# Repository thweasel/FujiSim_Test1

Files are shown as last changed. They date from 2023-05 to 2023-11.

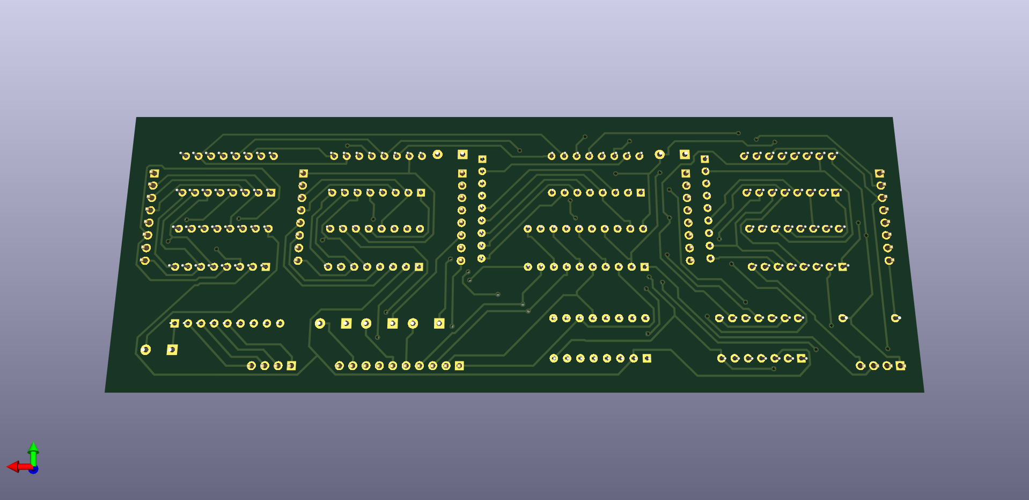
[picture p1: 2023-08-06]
KiCad7/Z80Bus_Adapters/ZXspectrum_Concept_v2/Impl/SPI-Z80-BUS_ZXspectrum_impl_V2/SPI-Z80-BUS-ZXSpectrum_impl_V2-back.png

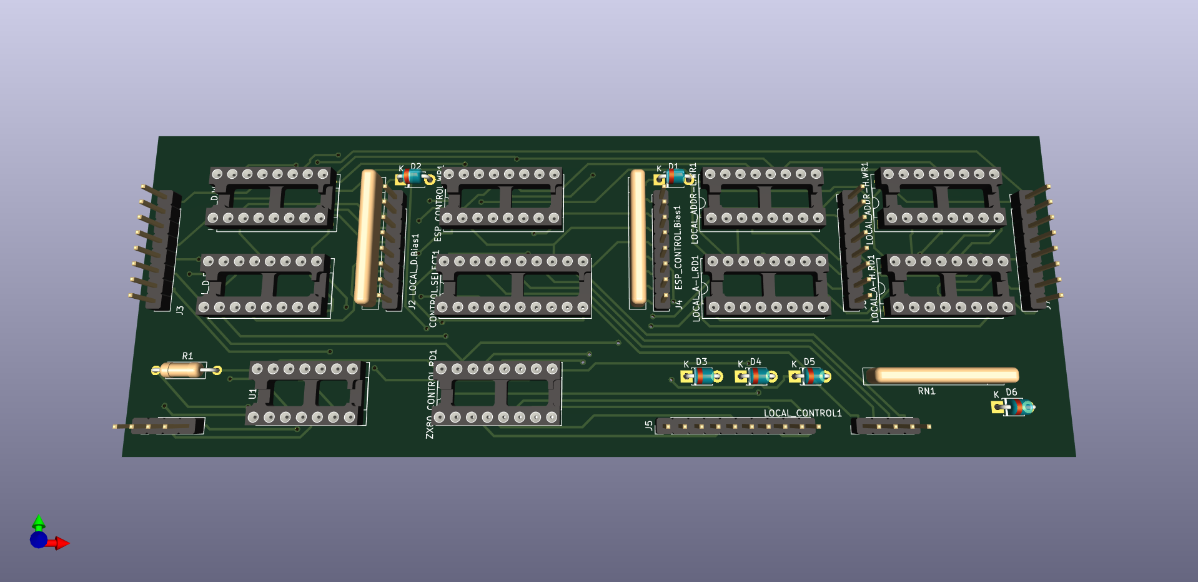
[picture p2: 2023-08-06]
KiCad7/Z80Bus_Adapters/ZXspectrum_Concept_v2/Impl/SPI-Z80-BUS_ZXspectrum_impl_V2/SPI-Z80-BUS-ZXSpectrum_impl_V2-front.png

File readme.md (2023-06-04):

# FujiNet Z80 simulation

The repo contains a SimulIDE simulator circuit with an Ardunio Mega to simulate Z80 and ESP signalling to the proposed bus interface.

Platform IO should be used within Visual Code to compile the project which is based on Arduino libraries.

## SimulIDE simulation settings

**SimulIDE Version0.4.15SR10**

To accurately simulate the SPI timing the properties of the simulation need to be edited before running. The "Simu Step ns" needs to be set to 10 in SimulIDE (right click empty diagram space, select properties from pop up menu). If simulation step time is not set correctly, then the ESP simulation will see bits missing when reading the Shift registers as the Clock and data signalling slips.

Don't forget to load the Firmware file into the Arduino! PlatformIO compiles the Arduino code to ./.pio/megaatmega2560/firmware.hex, when you click Build (not Build and program unless you are using real hardware!)

## KiCad ##

**KiCad version 7**

Going forward there are going to be different ways that the modules can be implemented and built. Therefore, a set of KiCad projects are in a modules folder, and then there is a folder for libraries for symbols/footprints; these are the building blocks. 

Each module project should have 2 schematics. The main project schematic has Pin headers etc. for a (test) PCB and a hierarchical schematic (not a project just a file) that contains the module's circuit. The module's hierarchical schematic file should not contain any connectors or "PCB stuff" just the parts needed for its function. So when making an adaptor the nested hierarchical schematic can be imported this hierarchical schematic without the extra "PCB stuff" cluttering the adaptor project PCBs. Module projects do not need a PCB design as they are imported into other projects that implement the PCB design and associated connectors etc. However, I like the idea of the modules being projects which have a PCB design to create a physical implementation for testing. In time all the modules could follow some common standard for PCB implementation these could be built and wired up ad-hoc.

A reference design is in the root KiCad folder, this shows how everything should connect up to make an adapter. There shouldn't really be a PCB for the reference design as the PCB design can (and did) influence the schematic. The reference design should be a pure, readable and simple expression of the requirements. So going forward a KiCad project should be created for the adaptor being built (in the adaptors folder), a simple way to copy all the settings is to save as from a similar project (e.g. template project). Now the modules schematics can be added to the adaptor project hierarchical schematics, add their hierarchical pins and wire/label as required.

If an adaptor uses a daughter board, then sub-projects in the adapter project need to be created (so they have their own PCB design). The sub-project is imported to the adaptor's main project as a hierarchical schematic so that the Electronic Rule Checker (ERC) can be used to validate the design.  Don't try to mark one-eye ball an adaptor design there are multiple busses and logic signals, and it's not far off a small computer; ERC is a valuable tool so use it. Another trick is to make use of the BUS net Class directives which apply styling to the connected bus, if a connection is missing there is no styling applied. I like to make it easy to see when things aren't connected as sometimes the ERC won't report a problem (more than one pin is connected makes it valid, even if it should be 3 pins connected).

## PCB fabrication with a 3018 CNC mill

The software pipeline:
- KiCad PCB design (export Gerber and Drill files)
- pcb2gcode (CAM, gerber to gcode)
- Universal Gcode Sender (runs the CNC mill controller)

The size and accuracy of the mill determine the PCB design rules to be used in the KiCad board setup. 

After trial and error, the following minimum limits have been found. A 0.5mm end mill (cutter) requires at a minimum, 0.4mm tracks and 0.6mm clearances. (This may change with pcb2gcode and some "git-gud"). With a 200-watt spindle motor, the following speeds and feeds for drilling and milling with a 0.5mm end mill.

Drilling
- Z cut -2mm
- Z Feedrate 30
- Spindle Speed 600 (~60% power)

Milling
- Z cut -0.15mm (board thickness varies)
- X-Y Feedrate 60 (20 or 40)
- Z Feedrate 30
- Spindle speed 800 (~80% power)

Going slower seems to be better for accuracy and success. Running the milling at max spindle speed and -1.5 cut resulted in a snapped 0.5mm end mill. Also, there is a lot of noise/vibration which makes the cutting just sound wrong.

The choice of tool for cutting the isolation paths seems to be split between V-bits and tiny straight-end mills. V-bits have a tip as narrow as 0.1mm but widen based on the angle (degrees) of the V. Assuming a perfectly flat board of even thickness, the tip + width at depth (0.1mm) isolation paths can be cut; assume a width of ~0.2mm approximately. However, perfect doesn't exist, the bit moves as Z height but the surface height changes (PCB thickness, bowing etc.). Therefore, the cut width changes as the V shape angle produces wider cuts as the tip moves deeper into the material. An end mill has a straight edge so cuts consistently at all depths below the surface. The only concern is cutting too deep and breaking the end mill, which is why a 0.5mm bit is used. End mills or Ball cutters go down to 0.2mm, but breakage risks increase. There is a similar problem with V bits, a 20-degree angle has a weaker tip than a 60-degree angle V bit. A wider angle V bit cut widens quicker with slight changes in depth. There is no perfect tool, just compromises and different workflows.

To counter problems with Vbits and depth of cut, Universal Gcode Sender has a plugin called "AutoLeveler". This plugin probes the height of the PCB at some given intervals. A height map is generated and the Z positions in the Gcode are modified. Thus, adding to the process of milling per side, probing pass and transformation of gcode. The accuracy of the trace is subject to the resolution of the probing, high accuracy means probing more points (long time). To conclude, there is room to achieve thinner track and clearance but for now, a simpler reliable approach trumps mastery of PCB milling.

Milling two-sided PCBs require the board to be flipped. This is an immediate alignment challenge which needs some thought. There are limitations imposed by CAM software features and the size of the CNC mill. Typically, the method seems to be prescribed by the CAM software. FlatCAM does inbox flips, the board is in the same place on the bed. To do this FlatCAM provides support to flip/mirror one of the Gerbers, alignment drill holes can be easily added. However, FlatCAM is too manual and buggy. 

Pcb2gcode enables "millproject" config files to be set up and reused between projects. The flip method used is a page turn by default, which requires the bed to be twice the size of the PCB. With a small bed and a big board, an in-place flip can be achieved by re-zeroing the origin on the X-axis after the flip.  Ideally, a jig should be used to maintain X-Y alignment or alternatively a pair of alignment holes evenly spaced from the centre lines. To make the flip alignment accurate an alignment hole can be drilled at 0,0 on the front; when flipped re-align to the hole and reset X 0. If you don't want to make holes in a PCB that is cut accurately to size, then zero on the corners (with the same tool fitted each time).

### KiCad PCB design/settings

Before laying out the PCB you need to set up the board settings, Design Rules and Net Classes. these should be set based on the achievable tollerances of the milling process.

Auto routing (FreeRouting) ignores the Design Rules, it only seems to follow NetClass rules, Edges and Margins (Rule areas on the margin layer). Therefore, you should fully define the board before placing components!

The process sets are:
Configure Design Rules and Net Classes
Draw an Edge box to the size of the PCB
Set Origin (file/drill/sheet) in the top left of the Edge box - place a *VIA on this spot
Create Margin boxes (+2mm) on the edges (Rule Area)
Layout components
Route tracks
Export Gerber and drill files (include the origins)
Export SVG as a CNC reference. F.Cu, B.Cu, User.Drawings, Edge.Cuts, F.Fab, B.Fab

*Directly placing a VIA on the Origin is blocked if it is in the margin. To get round this place the VIA outside the margin and move it to the Origin, this is permitted. Else you could adjust the shape of the marging and expose the corner.

Your PCB should have an Edge box the size of the PCB (stock or cut out). Marked out margins for Freerouting, 2mm seems reasonable. The Origin for sheets and files needs to be set at the top left of the Edge box. Origin can be corrected in pcb2gcode and milling just saves effort to do it right. Export to Gerber (Fabrication output), make sure "Use drill/place file origin" is checked. Hit Plot and Generate Drill Files. If you want to be tidy, export only the F.Cu, B.CU, and Edge_Cuts. You have a PCB file set to run through pcb2gcode.

The KiCad process is done!

### pcb2gcode CAM 

A "millproject" needs to be configured which enables milling a PCB with the Design Rules defined in KiCad. Yep, this is a circular dependency! 

Each Gerber needs to be addressed directly in the millproject file. Given the KiCad naming scheme, a bash script with a command line config can be used to wildcard the files. E.g. "pcb2gcode --front=*-F_Cu.gbr".

Read the wiki to create the millproject file https://github.com/pcb2gcode/pcb2gcode/wiki/Manual

Examples can be found in the pcb2gcode folder.

### Milling procedure

Set up a jig on the bed to hold the PCB.

Start with the front processes, which all have positive X co-ordinates

**Alignment**
- Align the mill and zero on the origin TOP-LEFT (same as KiCad)
- Use the PCB corner (marker pen) OR drill an alignment hole for the origin

**Drilling - front**
- Use drill bits that are the same length butted up in the collet, save  zeroing the Z axis per bit.
- Fit the first Tool (drill bit) in drill.ngc
- Touch the bit on the surface of the board and set Z to zero
- Run the drill.ngc
- Change bits as prompted.

**Milling - front**
- Fit the 0.5mm end mill
- Touch bit on the PCB surface and 0 Z axis
- Run Front.ngc

**Flip on Y (left to right)**
- The default flip/mirror axis in pcb2gcode is along the left edge of the - PCB, "turning a page in a book".
- Measure the X-axis length, move the mill from 0,0 lenght+X
- The mill should now be aligned to the TOP-RIGHT corner, opposite the origin used for the front.
- Tune positioning
- RESET X to 0

All cuts on the Back.ngc have a negative X coordinate so the mill runs from right to left.

**Milling - back**
- Fit the 0.5mm end mill
- Touch bit on the PCB surface and 0 Z axis
- Run Back.ngc

**Cut out - optional**
- Fit a cutting end mill (3.127mm)
- Touch bit on the PCB surface and 0 Z axis
- Run Outline.ngc

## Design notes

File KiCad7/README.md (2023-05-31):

# KiCad projects

Folders:

**Adapters** projects to make FujiNet adapters for different machines.

**Modules** parts to import into adapters for common functions e.g. SPI bus.

**Modules/*_impl** modules implemented as stand-alone PCBs with connectors

**ReferenceDesign** is an example of a completed adapter (schematic) for a ZX spectrum. This is the current concept design.

## New projects and path management

Some KiCad referencing information because managing paths is a tad annoying. Use relative pathing if you want anyone to open something you made. To do this all paths should start ${KIPRJMOD} which is the environment variable for the project folder ../ will take you back one layer as expected.

If you want to start a new Module or Adapter then you should open the template project and SAVE AS "name". This will copy the template and setting for you, and then there is less to set up.  Setting up from scratch requires libraries importing, Net classes, buses, PCB settings etc set up.

### Symbols

Name: esp32-wrover
Path: ${KIPRJMOD}/../../FujiNet_KiCadLibs/esp32-wrover-kicad-master/esp32-wrover.lib

Name: FujiNet_Memory_RAM
Path: ${KIPRJMOD}/../../FujiNet_KiCadLibs/FujiNet_Memory_RAM.kicad_sym

### Footprints
Name: esp32-wrover
Path: ${KIPRJMOD}/../../FujiNet_KiCadLibs/esp32-wrover-kicad-master/esp32-wrover.pretty

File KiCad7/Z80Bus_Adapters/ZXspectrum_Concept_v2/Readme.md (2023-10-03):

 
# ThatOldNerd's Revision 2 

ThatOldNerd's hard work to turn all the simulation circuit changes back into useable schematics and PCB layout.

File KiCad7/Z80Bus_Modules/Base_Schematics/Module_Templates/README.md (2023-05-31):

# New Module setup

Open the Modules project in this folder and SAVE AS "name" in the folder level above. Then open and SAVE AS the Module_Project_impl into the new Modules project (make a nested project).

A module has a project to manage the library paths. Some modules will need parts in the FujiNet Library. The nested project should have the same name as the module with _impl on the end. This sub-project is for creating an implementation of the module. Ideally, the PCB should have connectors/pin headers to enable testing of the module.

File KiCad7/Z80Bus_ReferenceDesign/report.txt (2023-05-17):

Change symbols J? J10 J9 J10 J1 from 'Connector_Generic:Conn_02x25_Top_Bottom' to 'Connector_Generic:Conn_02x25_Top_Bottom': OK

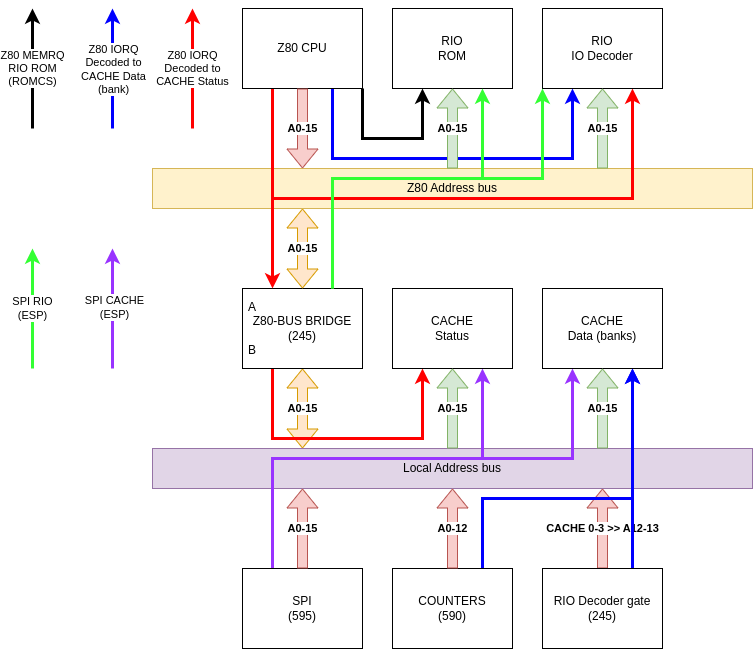
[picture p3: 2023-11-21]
Docs/Address BUS Block diagram Signal paths.drawio.png

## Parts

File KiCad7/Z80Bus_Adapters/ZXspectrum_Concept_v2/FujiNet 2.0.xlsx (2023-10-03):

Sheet: FujiNet 2.0
Designator | Description | Value
R1, R2, R3, R4 | R_Axial_DIN0207_L6.3mm_D2.5mm_P10.16mm_Horizontal | 22K
RN1 | R_Array_SIP9 | 4609M-101-103LF
C1, C2 | CP_Radial_D8.0mm_P5.00mm | 10uf
C3, C4, C5, C6 | C_Disc_D7.5mm_W2.5mm_P5.00mm | 0.1uf
D1, D2, D3, D4, D5, D6 | D_T-1_P5.08mm_Horizontal | 1N4148
Z80_AddLow, Z80_AddHigh | DIP-20_W7.62mm_Socket | 74HC245N
IC1 | DIP-14_W7.62mm_Socket | 7404N
IC2, IC5, IC7 | DIP-14_W7.62mm_Socket | 74HC32N
IC3 | DIP-14_W7.62mm_Socket | 7474N
IC4, IC6, IC8 | DIP-14_W7.62mm_Socket | 74HC08N
U1 - ESP32-WROVER-DEV-MODULE | Controller Daughter Board
U2 | DIP-14_W7.62mm | 74HC00
U3 | DIP-20_W7.62mm_Socket | 74HC244N
J1 | PinHeader_1x04_P2.54mm_Vertical
J2 - LOCAL_D | PinHeader_1x08_P2.54mm_Vertical
J3 - ESP_SPI_INT | PinHeader_1x08_P2.54mm_Vertical
J4 - ESP_CONTROL | PinHeader_1x08_P2.54mm_Vertical
J5 - Z80_CONTROL | PinHeader_1x10_P2.54mm_Vertical
J6 - LOCAL_A-L | PinHeader_1x08_P2.54mm_Vertical
J7 - LOCAL_A-H | PinHeader_1x08_P2.54mm_Vertical
J8 - DIAG-HOST_SYSTEM_BUS | PinHeader_1x40_P2.54mm_Vertical
J10 | PinHeader_1x04_P2.54mm_Vertical
EX_SPI1 | PinSocket_1x06_P2.54mm_Vertical
CACHE2 | PinSocket_1x14_P2.54mm_Vertical
LOCAL_CONTROL | PinHeader_1x04_P2.54mm_Vertical

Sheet: IOCACHE-128K
Designator | Description | Value
R1 | R_Axial_DIN0207_L6.3mm_D2.5mm_P10.16mm_Horizontal | 10K
IC1, IC2 | DIP-16_W7.62mm_Socket | 74HC590N
CACHE1 | DIP-32_W15.24mm_Socket | AS6C1008-55PCN
CACHE2 | PinSocket_1x24_P2.54mm_Vertical
CACHE3 | PinSocket_1x14_P2.54mm_Vertical

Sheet: RIO Board
Designator | Description | Value
R1, R2, R3 | R_Axial_DIN0207_L6.3mm_D2.5mm_P10.16mm_Horizontal | 10K
RIO_DECODER1 - Z80-RIO_DATA1 | DIP-20_W7.62mm_Socket | 74HC245N
RIO1 | DIP-32_W15.24mm_Socket | AS6C1008-55PCN
J1 | PinSocket_1x24_P2.54mm_Vertical
J2 | PinSocket_1x18_P2.54mm_Vertical

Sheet: SPI Buss
Designator | Description | Value
R1 | R_Axial_DIN0207_L6.3mm_D2.5mm_P10.16mm_Horizontal | 22K
RN1 - LOCAL_CONTROL.Bias, ESP_CONTROL.Bias1, LOCAL_D.Bias1 | R_Array_SIP9 | 10k
D1, D2, D3, D4, D5 | D_T-1_P5.08mm_Horizontal | 1N4148
U1 | DIP-14_W7.62mm_Socket | 74HC00
ZX80_CONTROL.RD1, LOCAL_D.RD1, LOCAL_A-H.RD1, LOCAL_A-L.RD1 | DIP-16_W7.62mm_Socket | 74HC165N
LOCAL_D.WR1, ESP_CONTROL.WR1, LOCAL_ADDR-H.WR1, LOCAL_ADDR-L.WR1 | DIP-16_W7.62mm_Socket | 74595N
CONTROL.SELECT1 | DIP-20_W7.62mm_Socket | 74HC244N
LOCAL_CONTROL1 | PinHeader_1x04_P2.54mm_Vertical
J1 | PinHeader_1x04_P2.54mm_Vertical
J2 - LOCAL_D | PinHeader_1x08_P2.54mm_Vertical
J3 - ESP_SPI_INT | PinHeader_1x08_P2.54mm_Vertical
J4 - ESP_CONTROL | PinHeader_1x08_P2.54mm_Vertical
J5 - Z80_CONTROL | PinHeader_1x10_P2.54mm_Vertical
J6 - LOCAL_A-L | PinHeader_1x08_P2.54mm_Vertical
J7 - LOCAL_A-H | PinHeader_1x08_P2.54mm_Vertical

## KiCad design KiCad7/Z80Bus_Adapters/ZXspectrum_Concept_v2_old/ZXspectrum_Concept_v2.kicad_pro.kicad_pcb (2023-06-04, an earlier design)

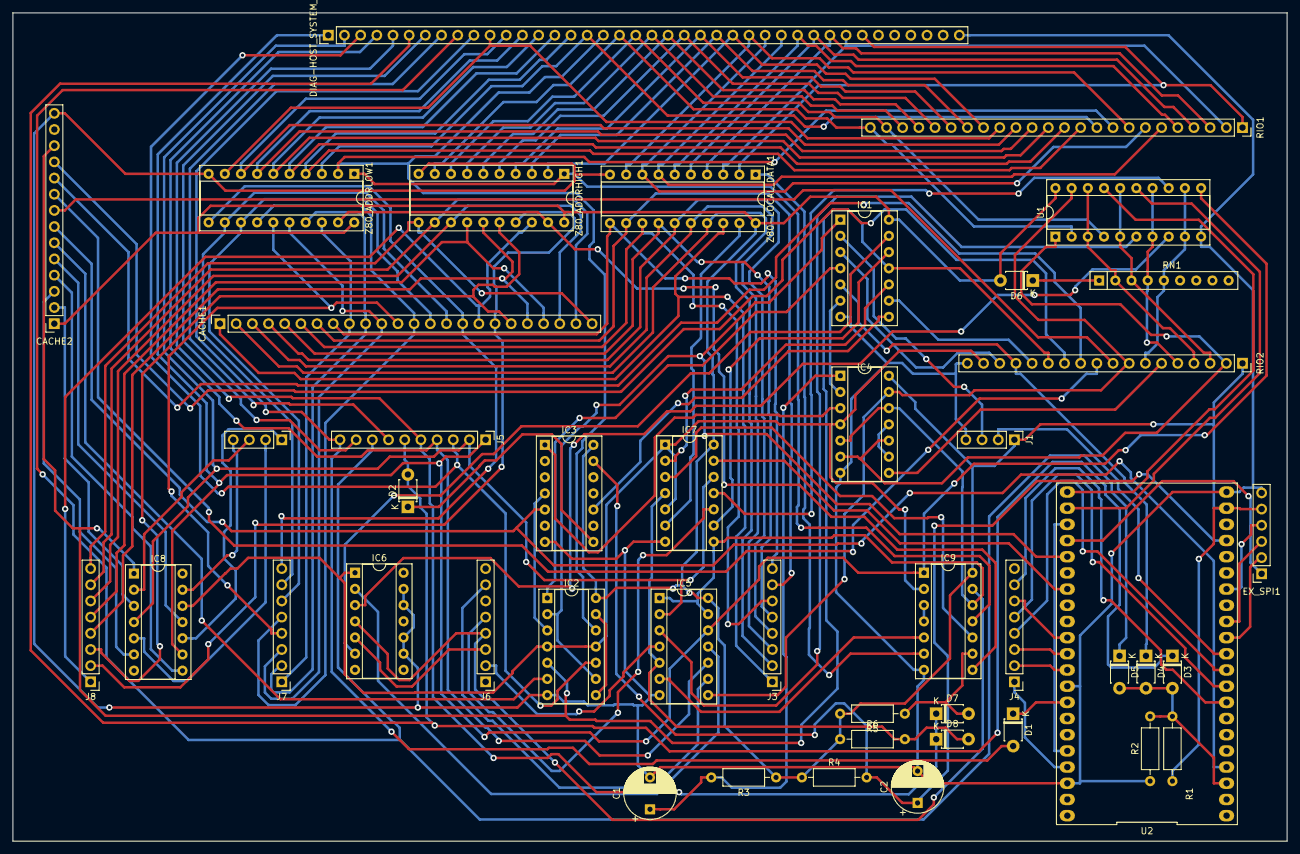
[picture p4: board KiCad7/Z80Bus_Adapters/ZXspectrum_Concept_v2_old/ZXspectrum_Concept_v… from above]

Board: 2 copper layers, 200.0 x 130.0 mm, 45 parts (0 on the bottom side), 139 nets.

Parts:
C1, C2: 10UF; CP_Radial_D8.0mm_P5.00mm
CACHE1: Conn_01x24_Socket; PinSocket_1x24_P2.54mm_Vertical
CACHE2: Conn_01x14_Socket; PinSocket_1x14_P2.54mm_Vertical
D1, D2, D3, D4, D5, D6, D7, D8: 1N4148; D_T-1_P5.08mm_Horizontal
DIAG-HOST_SYSTEM_BUS1: DIAG-HOST_SYSTEM_BUS; PinHeader_1x40_P2.54mm_Vertical
EX_SPI1: PinSocket_2.54mm; PinSocket_1x06_P2.54mm_Vertical
IC1: 7404N; DIP-14_W7.62mm_Socket
IC2, IC5, IC7, IC9: 74HC32N; DIP-14_W7.62mm_Socket
IC3: 7474N; DIP-14_W7.62mm_Socket
IC4, IC6, IC8: 74HC08N; DIP-14_W7.62mm_Socket
J1: PinHeader_2.54mm; PinHeader_1x04_P2.54mm_Vertical
J3: LOCAL_D; PinHeader_1x08_P2.54mm_Vertical
J4: ESP_SPI_INT; PinHeader_1x08_P2.54mm_Vertical
J5: Z80_CONTROL; PinHeader_1x10_P2.54mm_Vertical
J6: ESP_CONTROL; PinHeader_1x08_P2.54mm_Vertical
J7: LOCAL_A-L; PinHeader_1x08_P2.54mm_Vertical
J8: LOCAL_A-H; PinHeader_1x08_P2.54mm_Vertical
LOCAL_CONTROL1: LOCAL_CONTROL; PinHeader_1x04_P2.54mm_Vertical
R1, R2, R3, R4: 22K; R_Axial_DIN0207_L6.3mm_D2.5mm_P10.16mm_Horizontal
R5, R6: 10K; R_Axial_DIN0207_L6.3mm_D2.5mm_P10.16mm_Horizontal
RIO1: Conn_01x24_Socket; PinSocket_1x24_P2.54mm_Vertical
RIO2: Conn_01x18_Socket; PinSocket_1x18_P2.54mm_Vertical
RN1: 4609M-101-103LF; R_Array_SIP9
U1: 74HC244N; DIP-20_W7.62mm_Socket
U2: FREENOVE_ESP32-WROVER-DEV
Z80-LOCAL_DATA1, Z80_ADDRHIGH1, Z80_ADDRLOW1: 74HC245N; DIP-20_W7.62mm_Socket

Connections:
+5V: CACHE2.1, D6.2 (A), EX_SPI1.5, IC1.14 (VCC), IC2.14 (VCC), IC3.14 (VCC), IC4.14 (VCC), IC5.14 (VCC), IC7.14 (VCC), IC9.14 (VCC), J1.1, R1.2, R3.1, R4.1, R5.2, R6.1, RIO2.1, U1.20 (VCC), U2.20 (+5V), Z80-LOCAL_DATA1.20 (VCC), Z80_ADDRHIGH1.20 (VCC), Z80_ADDRLOW1.20 (VCC)
/CACHE connector/CACHE_CONTROL.A16: CACHE2.2, IC8.3
/CACHE connector/CACHE_CONTROL.CS: CACHE2.5, IC8.11
/CACHE connector/CACHE_CONTROL.DATASTATUS+PERM_Z80_IORQ: CACHE2.6, IC2.6
/CACHE connector/CACHE_CONTROL.OE: CACHE2.4, IC8.8
/CACHE connector/CACHE_CONTROL.WE: CACHE2.3, IC8.6
/CACHE connector/CACHE_DATASTATUS: CACHE2.12, IC1.11, IC2.5, IC8.1, RIO2.13
/CACHE connector/CACHE_SEL_0: CACHE2.8, RIO2.9
/CACHE connector/CACHE_SEL_1: CACHE2.9, RIO2.10
/CACHE connector/CACHE_SEL_2: CACHE2.10, RIO2.11
/CACHE connector/CACHE_SEL_3: CACHE2.11, RIO2.12
/CACHE connector/LOCAL_A0: CACHE1.9, J7.1, Z80_ADDRLOW1.18 (B0)
/CACHE connector/LOCAL_A1: CACHE1.10, J7.2, Z80_ADDRLOW1.17 (B1)
/CACHE connector/LOCAL_A2: CACHE1.11, J7.3, Z80_ADDRLOW1.16 (B2)
/CACHE connector/LOCAL_A3: CACHE1.12, J7.4, Z80_ADDRLOW1.15 (B3)
/CACHE connector/LOCAL_A4: CACHE1.13, J7.5, Z80_ADDRLOW1.14 (B4)
/CACHE connector/LOCAL_A5: CACHE1.14, J7.6, Z80_ADDRLOW1.13 (B5)
/CACHE connector/LOCAL_A6: CACHE1.15, J7.7, Z80_ADDRLOW1.12 (B6)
/CACHE connector/LOCAL_A7: CACHE1.16, J7.8, Z80_ADDRLOW1.11 (B7)
/CACHE connector/LOCAL_A8: CACHE1.17, J8.1, Z80_ADDRHIGH1.18 (B0)
/CACHE connector/LOCAL_A9: CACHE1.18, J8.2, Z80_ADDRHIGH1.17 (B1)
/CACHE connector/LOCAL_A10: CACHE1.19, J8.3, Z80_ADDRHIGH1.16 (B2)
/CACHE connector/LOCAL_A11: CACHE1.20, J8.4, Z80_ADDRHIGH1.15 (B3)
/CACHE connector/LOCAL_A12: CACHE1.21, J8.5, Z80_ADDRHIGH1.14 (B4)
/CACHE connector/LOCAL_A13: CACHE1.22, J8.6, Z80_ADDRHIGH1.13 (B5)
/CACHE connector/LOCAL_A14: CACHE1.23, J8.7, Z80_ADDRHIGH1.12 (B6)
/CACHE connector/LOCAL_A15: CACHE1.24, J8.8, Z80_ADDRHIGH1.11 (B7)
/CACHE connector/LOCAL_D0: CACHE1.1, J3.1, Z80-LOCAL_DATA1.18 (B0)
/CACHE connector/LOCAL_D1: CACHE1.2, J3.2, Z80-LOCAL_DATA1.17 (B1)
/CACHE connector/LOCAL_D2: CACHE1.3, J3.3, Z80-LOCAL_DATA1.16 (B2)
/CACHE connector/LOCAL_D3: CACHE1.4, J3.4, Z80-LOCAL_DATA1.15 (B3)
/CACHE connector/LOCAL_D4: CACHE1.5, J3.5, Z80-LOCAL_DATA1.14 (B4)
/CACHE connector/LOCAL_D5: CACHE1.6, J3.6, Z80-LOCAL_DATA1.13 (B5)
/CACHE connector/LOCAL_D6: CACHE1.7, J3.7, Z80-LOCAL_DATA1.12 (B6)
/CACHE connector/LOCAL_D7: CACHE1.8, J3.8, Z80-LOCAL_DATA1.11 (B7)
/CACHE connector/Z80_HARDLOCK: CACHE2.7, IC3.5 (Q), U2.4 (GPIO39)
/CORE/ESP_HARDLOCK: IC1.1, IC2.2, IC2.9, U2.26 (GPIO2)
/CORE/ESP_INT: D3.2 (A), D4.2 (A), D5.2 (A), R1.1, R2.2, U2.3 (GPIO36)
/CORE/ESP_PULSE: J1.2, U2.11 (GPIO27)
/CORE/ESP_ROMSEL_0: U1.15 (2A1), U2.23 (GPIO7)
/CORE/ESP_ROMSEL_1: U1.17 (2A0), U2.22 (GPIO6)
/CORE/ESP_ROM_WR_PROTECT: IC7.13, U2.28 (GPIO4)
/CORE/ESP_SPI_INT.CE: J4.6, U2.31 (GPIO5)
/CORE/ESP_SPI_INT.MISO: J4.2, U2.33 (GPIO19)
/CORE/ESP_SPI_INT.MOSI: J4.1, U2.39 (GPIO23)
/CORE/ESP_SPI_INT.OE: J4.7, U2.8 (GPIO33)
/CORE/ESP_SPI_INT.PL: J4.5, U2.9 (GPIO25)
/CORE/ESP_SPI_INT.SCK: J4.3, U2.32 (GPIO18)
/CORE/ESP_SPI_INT.STC: J4.4, U2.10 (GPIO26)
/CORE/ESP_WAIT_RESET: C2.1, IC3.13 (~R), R4.2, U2.18 (GPIO11)
/CORE/EX_MISO: EX_SPI1.3, U2.13 (GPIO12)
/CORE/EX_MOSI: EX_SPI1.4, U2.15 (GPIO13)
/CORE/EX_SCK: EX_SPI1.2, U2.12 (GPIO14)
/CORE/EX_SS: EX_SPI1.1, U2.25 (GPIO8)
/CORE/SD_CARD_SS: U2.24 (GPIO15), U2.38 (GPIO22)
/CORE/Z80_HARDLOCK_RESET: D4.1 (K), IC1.5, RIO2.15
/GLUE/!ESP_HARDLOCK: IC1.2, J1.3
/GLUE/CLR_Z80_HARDLOCK: IC3.1 (~R), IC4.3
/GLUE/ESP_IOD_CONFIG: IC4.5, IC4.12, IC5.1, IC5.13, IC7.8, IC9.12
/GLUE/PERM_Z80_IORQ: IC2.4, IC2.11, IC4.4, IC6.1, IC7.1, IC7.5, IC8.12, IC9.2, RIO2.17
/GLUE/PRE_Z80_HARDLOCK: IC2.3, IC3.4 (~S)
/GLUE/RIO CONTROL/ROM_WR_PROTECT+Z80_WR: IC7.11, U1.13 (2A2)
/GLUE/RIO CONTROL/Z80_RD+ESP_IOD_CONFIG+PERM_Z80_IORQ: IC6.3, U1.8 (1A3)
/GLUE/RIO CONTROL/Z80_WR+ESP_IOD_CONFIG: IC5.3, U1.6 (1A2)
/GLUE/RIO_CONTROL.A14: RIO2.4, RN1.2 (R1), U1.3 (2Y0), U1.18 (1Y0)
/GLUE/RIO_CONTROL.A15: RIO2.3, RN1.3 (R2), U1.5 (2Y1), U1.16 (1Y1)
/GLUE/RIO_CONTROL.A16: IC4.6, IC4.10, RIO2.2, U1.1 (1OE)
/GLUE/RIO_CONTROL.CE: IC4.8, RIO2.6
/GLUE/RIO_CONTROL.OE: RIO2.7, RN1.5 (R4), U1.9 (2Y3), U1.12 (1Y3)
/GLUE/RIO_CONTROL.ROM_RDY: IC4.13, IC5.8, RIO2.8, U1.19 (2OE)
/GLUE/RIO_CONTROL.WE: RIO2.5, RN1.4 (R3), U1.7 (2Y2), U1.14 (1Y2)
/GLUE/WAIT_IO: IC1.9, RIO2.14
/GLUE/Z80 BUS CONTROL/!CACHE_DATASTATUS: IC1.10, IC7.2
/GLUE/Z80 BUS CONTROL/Z80_ADD_CONNECT: D7.2 (A), IC9.9, R5.1
/GLUE/Z80 BUS CONTROL/Z80_DATA_CONNECT: D8.2 (A), IC5.5, IC7.4, R6.2
/GLUE/Z80_BUS_CONTROL.Z80_ADD_DIR: IC9.11, Z80_ADDRHIGH1.1 (A->B), Z80_ADDRLOW1.1 (A->B)
/GLUE/Z80_BUS_CONTROL.Z80_ADD_OE: IC9.8, Z80_ADDRHIGH1.19 (CE), Z80_ADDRLOW1.19 (CE)
/GLUE/Z80_BUS_CONTROL.Z80_DATA_DIR: IC9.6, Z80-LOCAL_DATA1.1 (A->B)
/GLUE/Z80_BUS_CONTROL.Z80_DATA_OE: IC7.6, Z80-LOCAL_DATA1.19 (CE)
/GLUE/Z80_HARDLOCK_SET: IC1.3, RIO2.16
/RIO connector/Z80_A0: DIAG-HOST_SYSTEM_BUS1.18, IC2.12, RIO1.9, Z80_ADDRLOW1.2 (A0)
/RIO connector/Z80_A1: DIAG-HOST_SYSTEM_BUS1.17, RIO1.10, Z80_ADDRLOW1.3 (A1)
/RIO connector/Z80_A2: DIAG-HOST_SYSTEM_BUS1.16, RIO1.11, Z80_ADDRLOW1.4 (A2)
/RIO connector/Z80_A3: DIAG-HOST_SYSTEM_BUS1.15, RIO1.12, Z80_ADDRLOW1.5 (A3)
/RIO connector/Z80_A4: DIAG-HOST_SYSTEM_BUS1.14, RIO1.13, Z80_ADDRLOW1.6 (A4)
/RIO connector/Z80_A5: DIAG-HOST_SYSTEM_BUS1.13, RIO1.14, Z80_ADDRLOW1.7 (A5)
/RIO connector/Z80_A6: DIAG-HOST_SYSTEM_BUS1.12, RIO1.15, Z80_ADDRLOW1.8 (A6)
/RIO connector/Z80_A7: DIAG-HOST_SYSTEM_BUS1.11, RIO1.16, Z80_ADDRLOW1.9 (A7)
/RIO connector/Z80_A8: DIAG-HOST_SYSTEM_BUS1.26, RIO1.17, Z80_ADDRHIGH1.2 (A0)
/RIO connector/Z80_A9: DIAG-HOST_SYSTEM_BUS1.25, RIO1.18, Z80_ADDRHIGH1.3 (A1)
/RIO connector/Z80_A10: DIAG-HOST_SYSTEM_BUS1.24, RIO1.19, Z80_ADDRHIGH1.4 (A2)
/RIO connector/Z80_A11: DIAG-HOST_SYSTEM_BUS1.23, RIO1.20, Z80_ADDRHIGH1.5 (A3)
/RIO connector/Z80_A12: DIAG-HOST_SYSTEM_BUS1.22, RIO1.21, Z80_ADDRHIGH1.6 (A4)
/RIO connector/Z80_A13: DIAG-HOST_SYSTEM_BUS1.21, RIO1.22, Z80_ADDRHIGH1.7 (A5)
/RIO connector/Z80_A14: DIAG-HOST_SYSTEM_BUS1.20, RIO1.23, U1.4 (1A1), Z80_ADDRHIGH1.8 (A6)
/RIO connector/Z80_A15: DIAG-HOST_SYSTEM_BUS1.19, RIO1.24, U1.2 (1A0), Z80_ADDRHIGH1.9 (A7)
/RIO connector/Z80_D0: DIAG-HOST_SYSTEM_BUS1.34, RIO1.1, Z80-LOCAL_DATA1.2 (A0)
/RIO connector/Z80_D1: DIAG-HOST_SYSTEM_BUS1.33, RIO1.2, Z80-LOCAL_DATA1.3 (A1)
/RIO connector/Z80_D2: DIAG-HOST_SYSTEM_BUS1.32, RIO1.3, Z80-LOCAL_DATA1.4 (A2)
/RIO connector/Z80_D3: DIAG-HOST_SYSTEM_BUS1.31, RIO1.4, Z80-LOCAL_DATA1.5 (A3)
/RIO connector/Z80_D4: DIAG-HOST_SYSTEM_BUS1.30, RIO1.5, Z80-LOCAL_DATA1.6 (A4)
/RIO connector/Z80_D5: DIAG-HOST_SYSTEM_BUS1.29, RIO1.6, Z80-LOCAL_DATA1.7 (A5)
/RIO connector/Z80_D6: DIAG-HOST_SYSTEM_BUS1.28, RIO1.7, Z80-LOCAL_DATA1.8 (A6)
/RIO connector/Z80_D7: DIAG-HOST_SYSTEM_BUS1.27, RIO1.8, Z80-LOCAL_DATA1.9 (A7)
/SPI connector/ESP_CONTROL.BUSRQ: IC7.10, J6.5
/SPI connector/ESP_CONTROL.IORQ: IC6.5, J6.3
/SPI connector/ESP_CONTROL.MEMRQ: IC6.4, IC9.13, J6.4
/SPI connector/ESP_CONTROL.ROMCS: IC5.9, J6.7
/SPI connector/ESP_CONTROL.WR: IC5.4, J6.2
/SPI connector/LOCAL_CONTROL.IORQ: IC8.2, LOCAL_CONTROL1.3
/SPI connector/LOCAL_CONTROL.MEMRQ: IC8.13, LOCAL_CONTROL1.4
/SPI connector/LOCAL_CONTROL.RD: IC8.10, LOCAL_CONTROL1.1
/SPI connector/LOCAL_CONTROL.WR: IC8.5, LOCAL_CONTROL1.2
/SPI connector/Z80_CONTROL.BUSACK: D5.1 (K), DIAG-HOST_SYSTEM_BUS1.9, J5.8
/SPI connector/Z80_CONTROL.BUSRQ: D7.1 (K), D8.1 (K), DIAG-HOST_SYSTEM_BUS1.5, J5.5
/SPI connector/Z80_CONTROL.IORQ: DIAG-HOST_SYSTEM_BUS1.3, IC2.10, J5.3
/SPI connector/Z80_CONTROL.MEMRQ: DIAG-HOST_SYSTEM_BUS1.4, IC5.10, J5.4
/SPI connector/Z80_CONTROL.NMI: DIAG-HOST_SYSTEM_BUS1.7, J5.9
/SPI connector/Z80_CONTROL.RD: DIAG-HOST_SYSTEM_BUS1.1, IC5.12, IC8.9, IC9.1, J5.1, U1.11 (2A3)
/SPI connector/Z80_CONTROL.RESET: D1.2 (A), DIAG-HOST_SYSTEM_BUS1.10, J5.10
/SPI connector/Z80_CONTROL.ROMCS: DIAG-HOST_SYSTEM_BUS1.8, J5.7
/SPI connector/Z80_CONTROL.WAIT: D2.2 (A), D3.1 (K), DIAG-HOST_SYSTEM_BUS1.6, J5.6
/SPI connector/Z80_CONTROL.WR: DIAG-HOST_SYSTEM_BUS1.2, IC5.2, IC7.12, IC8.4, J5.2
GND: C1.2, C2.2, CACHE2.14, DIAG-HOST_SYSTEM_BUS1.40, EX_SPI1.6, IC1.7 (GND), IC2.7 (GND), IC3.7 (GND), IC4.7 (GND), IC5.7 (GND), IC6.9, IC6.10, IC6.12, IC6.13, IC7.7 (GND), IC9.7 (GND), J1.4, R2.1, RIO2.18, U1.10 (GND), U2.21 (GND), U2.34 (GND), U2.40 (GND), Z80-LOCAL_DATA1.10 (GND), Z80_ADDRHIGH1.10 (GND), Z80_ADDRLOW1.10 (GND)
unnamed: C1.1, IC4.1, R3.2
unnamed: D1.1 (K), U2.35 (GPIO21)
unnamed: D2.1 (K), IC3.8 (~Q)
unnamed: D6.1 (K), RN1.1 (common)
unnamed: IC1.4, IC2.1
unnamed: IC1.6, IC4.2
unnamed: IC1.12, IC7.9
unnamed: IC1.13, IC6.6
unnamed: IC2.8, IC2.13
unnamed: IC1.8, IC3.10 (~S)
unnamed: IC4.9, IC4.11
unnamed: IC5.6, IC9.5
unnamed: IC5.11, IC6.2
unnamed: IC7.3, IC9.10
unnamed: IC9.3, IC9.4

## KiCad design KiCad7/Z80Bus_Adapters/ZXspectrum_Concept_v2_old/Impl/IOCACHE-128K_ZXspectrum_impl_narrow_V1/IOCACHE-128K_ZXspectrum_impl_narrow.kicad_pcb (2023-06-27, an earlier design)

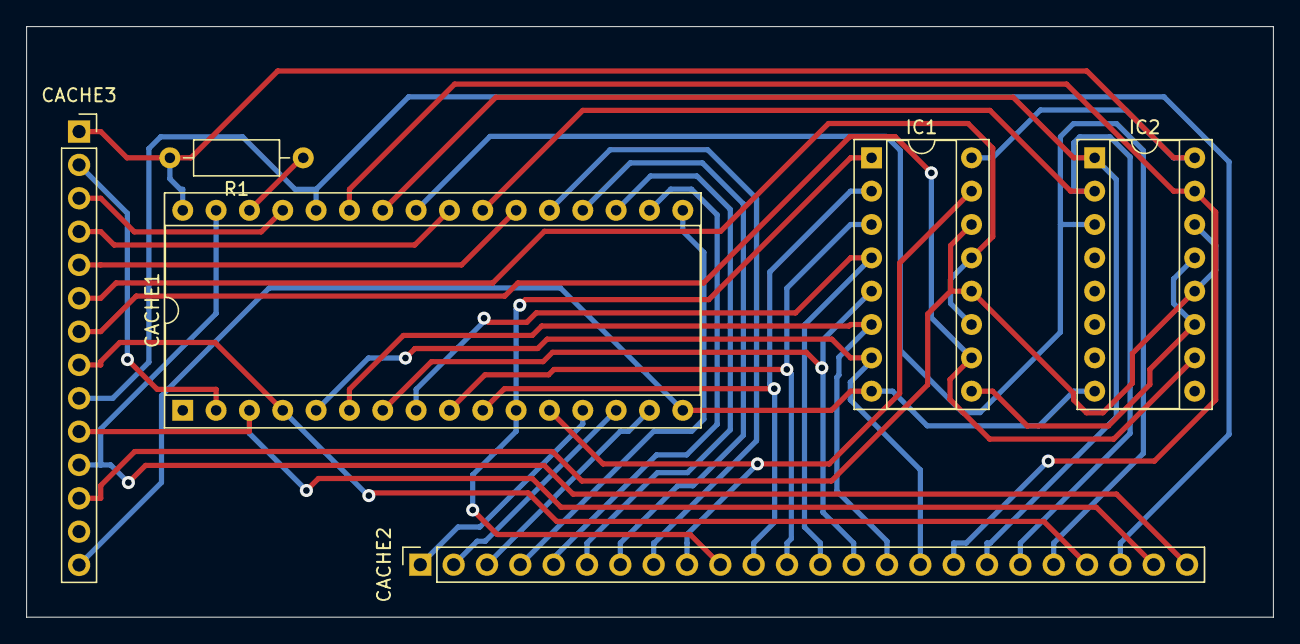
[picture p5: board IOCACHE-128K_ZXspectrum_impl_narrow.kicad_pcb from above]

Board: 2 copper layers, 95.0 x 45.0 mm, 6 parts (0 on the bottom side), 35 nets.

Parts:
CACHE1: AS6C1008-55PCN; DIP-32_W15.24mm_Socket
CACHE2: Conn_01x24_Socket; PinSocket_1x24_P2.54mm_Vertical
CACHE3: Conn_01x14_Socket; PinSocket_1x14_P2.54mm_Vertical
IC1, IC2: 74HC590N; DIP-16_W7.62mm_Socket
R1: 10K; R_Axial_DIN0207_L6.3mm_D2.5mm_P10.16mm_Horizontal

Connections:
+5V: CACHE1.32 (VCC), CACHE3.1, IC1.16 (VCC), IC2.16 (VCC), R1.2
/IOCACHE-128K_ZXspectrum/CACHE_CE2: CACHE1.30 (CE2#), R1.1
/IOCACHE-128K_ZXspectrum/CACHE_CONTROL.A16: CACHE1.2 (A16), CACHE3.2
/IOCACHE-128K_ZXspectrum/CACHE_CONTROL.CS: CACHE1.22 (CE#), CACHE3.5
/IOCACHE-128K_ZXspectrum/CACHE_CONTROL.DATASTATUS+PERM_Z80_IORQ: CACHE3.6, IC1.11 (CPC), IC1.13 (CPR)
/IOCACHE-128K_ZXspectrum/CACHE_CONTROL.OE: CACHE1.24 (OE#), CACHE3.4
/IOCACHE-128K_ZXspectrum/CACHE_CONTROL.WE: CACHE1.29 (WE#), CACHE3.3
/IOCACHE-128K_ZXspectrum/CACHE_DATASTATUS: CACHE3.12, IC1.12 (~CE), IC1.14 (~OE), IC2.12 (~CE), IC2.14 (~OE)
/IOCACHE-128K_ZXspectrum/LOCAL_A0: CACHE1.12 (A0), CACHE2.9, IC1.15 (Q0)
/IOCACHE-128K_ZXspectrum/LOCAL_A1: CACHE1.11 (A1), CACHE2.10, IC1.1 (Q1)
/IOCACHE-128K_ZXspectrum/LOCAL_A2: CACHE1.10 (A2), CACHE2.11, IC1.2 (Q2)
/IOCACHE-128K_ZXspectrum/LOCAL_A3: CACHE1.9 (A3), CACHE2.12, IC1.3 (Q3)
/IOCACHE-128K_ZXspectrum/LOCAL_A4: CACHE1.8 (A4), CACHE2.13, IC1.4 (Q4)
/IOCACHE-128K_ZXspectrum/LOCAL_A5: CACHE1.7 (A5), CACHE2.14, IC1.5 (Q5)
/IOCACHE-128K_ZXspectrum/LOCAL_A6: CACHE1.6 (A6), CACHE2.15, IC1.6 (Q6)
/IOCACHE-128K_ZXspectrum/LOCAL_A7: CACHE1.5 (A7), CACHE2.16, IC1.7 (Q7)
/IOCACHE-128K_ZXspectrum/LOCAL_A8: CACHE1.27 (A8), CACHE2.17, IC2.15 (Q0)
/IOCACHE-128K_ZXspectrum/LOCAL_A9: CACHE1.26 (A9), CACHE2.18, IC2.1 (Q1)
/IOCACHE-128K_ZXspectrum/LOCAL_A10: CACHE1.23 (A10), CACHE2.19, IC2.2 (Q2)
/IOCACHE-128K_ZXspectrum/LOCAL_A11: CACHE1.25 (A11), CACHE2.20, IC2.3 (Q3)
/IOCACHE-128K_ZXspectrum/LOCAL_A12: CACHE1.4 (A12), CACHE2.21, CACHE3.8
/IOCACHE-128K_ZXspectrum/LOCAL_A13: CACHE1.28 (A13), CACHE2.22, CACHE3.9
/IOCACHE-128K_ZXspectrum/LOCAL_A14: CACHE1.3 (A14), CACHE2.23, CACHE3.10
/IOCACHE-128K_ZXspectrum/LOCAL_A15: CACHE1.31 (A15), CACHE2.24, CACHE3.11
/IOCACHE-128K_ZXspectrum/LOCAL_D0: CACHE1.13 (DQ0), CACHE2.1
/IOCACHE-128K_ZXspectrum/LOCAL_D1: CACHE1.14 (DQ1), CACHE2.2
/IOCACHE-128K_ZXspectrum/LOCAL_D2: CACHE1.15 (DQ2), CACHE2.3
/IOCACHE-128K_ZXspectrum/LOCAL_D3: CACHE1.17 (DQ3), CACHE2.4
/IOCACHE-128K_ZXspectrum/LOCAL_D4: CACHE1.18 (DQ4), CACHE2.5
/IOCACHE-128K_ZXspectrum/LOCAL_D5: CACHE1.19 (DQ5), CACHE2.6
/IOCACHE-128K_ZXspectrum/LOCAL_D6: CACHE1.20 (DQ6), CACHE2.7
/IOCACHE-128K_ZXspectrum/LOCAL_D7: CACHE1.21 (DQ7), CACHE2.8
/IOCACHE-128K_ZXspectrum/Z80_HARDLOCK: CACHE3.7, IC1.10 (~MRC), IC2.10 (~MRC)
GND: CACHE1.16 (VSS), CACHE3.14, IC1.8 (GND), IC2.8 (GND)
unnamed: IC1.9 (~RCO), IC2.11 (CPC), IC2.13 (CPR)

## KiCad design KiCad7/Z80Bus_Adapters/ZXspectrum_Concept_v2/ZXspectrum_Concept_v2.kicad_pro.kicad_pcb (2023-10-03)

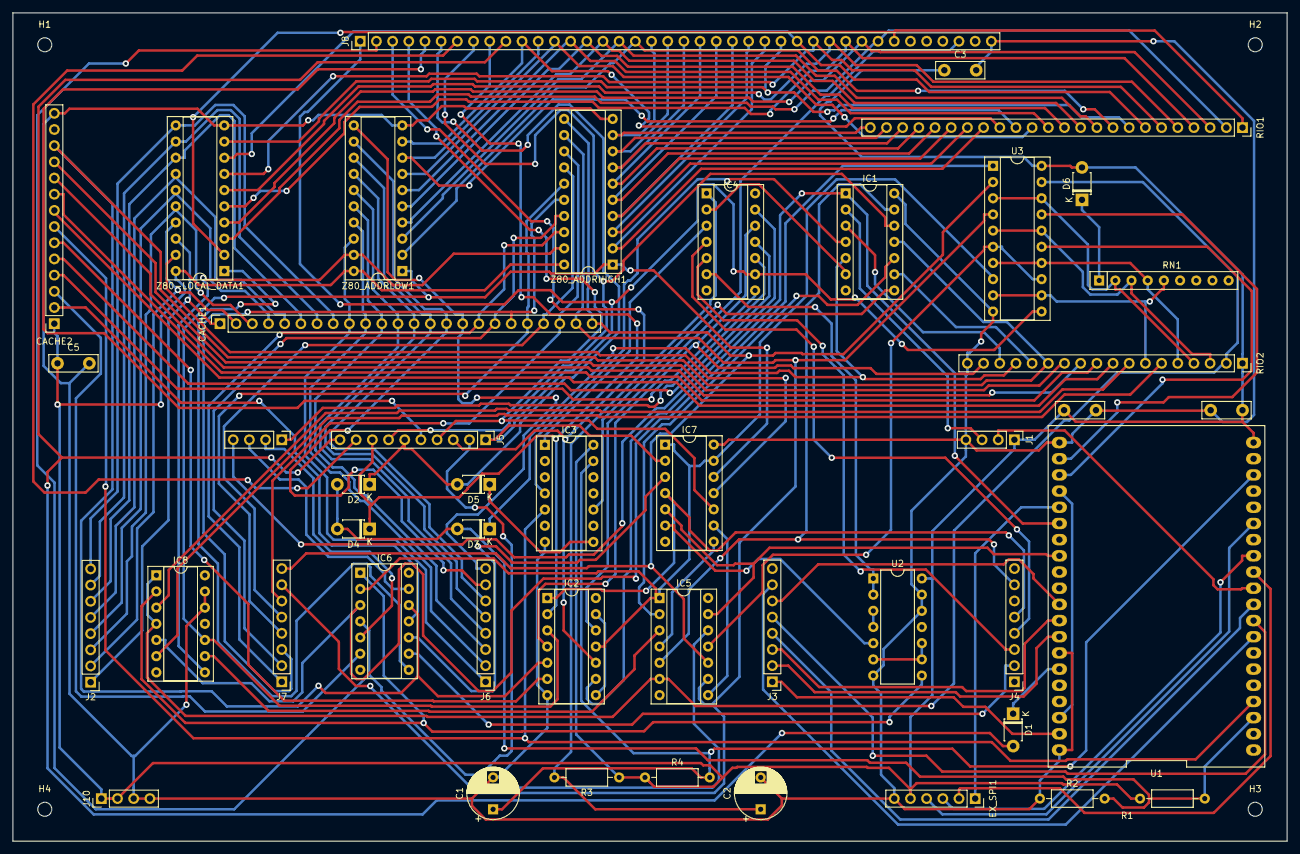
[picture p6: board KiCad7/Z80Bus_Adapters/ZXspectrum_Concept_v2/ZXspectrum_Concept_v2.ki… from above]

Board: 2 copper layers, 200.0 x 130.0 mm, 50 parts (0 on the bottom side), 138 nets.

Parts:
C1, C2: 10UF; CP_Radial_D8.0mm_P5.00mm
C3, C4, C5, C6: 0.1uf; C_Disc_D7.5mm_W2.5mm_P5.00mm
CACHE1: Conn_01x24_Socket; PinSocket_1x24_P2.54mm_Vertical
CACHE2: Conn_01x14_Socket; PinSocket_1x14_P2.54mm_Vertical
D1, D2, D3, D4, D5, D6: 1N4148; D_T-1_P5.08mm_Horizontal
EX_SPI1: PinSocket_2.54mm; PinSocket_1x06_P2.54mm_Vertical
H1, H2, H3, H4: MountingHole; MountingHole_2.2mm_M2
IC1: 7404N; DIP-14_W7.62mm_Socket
IC2, IC5, IC7: 74HC32N; DIP-14_W7.62mm_Socket
IC3: 7474N; DIP-14_W7.62mm_Socket
IC4, IC6, IC8: 74HC08N; DIP-14_W7.62mm_Socket
J1: PinHeader_2.54mm; PinHeader_1x04_P2.54mm_Vertical
J2: LOCAL_D; PinHeader_1x08_P2.54mm_Vertical
J3: ESP_SPI_INT; PinHeader_1x08_P2.54mm_Vertical
J4: ESP_CONTROL; PinHeader_1x08_P2.54mm_Vertical
J5: Z80_CONTROL; PinHeader_1x10_P2.54mm_Vertical
J6: LOCAL_A-L; PinHeader_1x08_P2.54mm_Vertical
J7: LOCAL_A-H; PinHeader_1x08_P2.54mm_Vertical
J8: DIAG-HOST_SYSTEM_BUS; PinHeader_1x40_P2.54mm_Vertical
J10: Conn_01x04; PinHeader_1x04_P2.54mm_Vertical
LOCAL_CONTROL1: LOCAL_CONTROL; PinHeader_1x04_P2.54mm_Vertical
R1, R2, R3, R4: 22K; R_Axial_DIN0207_L6.3mm_D2.5mm_P10.16mm_Horizontal
RIO1: Conn_01x24_Socket; PinSocket_1x24_P2.54mm_Vertical
RIO2: Conn_01x18_Socket; PinSocket_1x18_P2.54mm_Vertical
RN1: 4609M-101-103LF; R_Array_SIP9
U1: FREENOVE_ESP32-WROVER-DEV; Controller Daughter Board
U2: 74HC00; DIP-14_W7.62mm
U3: 74HC244N; DIP-20_W7.62mm_Socket
Z80-LOCAL_DATA1, Z80_ADDRHIGH1, Z80_ADDRLOW1: 74HC245N; DIP-20_W7.62mm_Socket

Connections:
+5V: C3.1, C4.1, C5.1, C6.1, CACHE2.1, D6.2 (A), EX_SPI1.5, IC3.14 (VCC), J1.1, J10.1, J10.2, R1.2, R3.1, R4.1, RIO2.1, U1.20 (+5V), U2.14 (VCC), U3.20 (VCC), Z80-LOCAL_DATA1.20 (VCC), Z80_ADDRHIGH1.20 (VCC), Z80_ADDRLOW1.20 (VCC)
/CACHE_CONTROL.A16: CACHE2.2, IC6.11
/CACHE_CONTROL.CS: CACHE2.5, IC4.11
/CACHE_CONTROL.DATASTATUS+PERM_Z80_IORQ: CACHE2.6, IC2.6
/CACHE_CONTROL.OE: CACHE2.4, IC4.8
/CACHE_CONTROL.WE: CACHE2.3, IC6.6
/CACHE_DATASTATUS: CACHE2.12, IC1.11, IC2.5, IC6.12, RIO2.13
/CACHE_SEL_0: CACHE2.8, RIO2.9
/CACHE_SEL_1: CACHE2.9, RIO2.10
/CACHE_SEL_2: CACHE2.10, RIO2.11
/CACHE_SEL_3: CACHE2.11, RIO2.12
/ESP32WRover/ESP_INT: D2.2 (A), D3.2 (A), D4.2 (A), R1.1, R2.2, U1.3 (GPIO36)
/ESP32WRover/EX_MISO: EX_SPI1.3, U1.13 (GPIO12)
/ESP32WRover/EX_MOSI: EX_SPI1.4, U1.15 (GPIO13)
/ESP32WRover/EX_SCK: EX_SPI1.2, U1.12 (GPIO14)
/ESP32WRover/EX_SS: EX_SPI1.1, U1.25 (GPIO8)
/ESP32WRover/SD_CARD_SS: U1.24 (GPIO15), U1.38 (GPIO22)
/ESP PULSE: J1.2, U1.11 (GPIO27)
/ESP_CONTROL.BUSRQ: IC2.1, IC7.4, J4.5
/ESP_CONTROL.IORQ: IC4.5, J4.3
/ESP_CONTROL.MEMRQ: IC4.4, J4.4
/ESP_CONTROL.ROMCS: IC1.13, IC5.5, J4.7
/ESP_CONTROL.WR: IC6.9, J4.2
/ESP_HARDLOCK: IC1.1, IC2.9, U1.26 (GPIO2)
/ESP_RIO_PROTECT: IC5.13, IC7.5, U1.28 (GPIO4)
/ESP_ROMSEL_0: U1.23 (GPIO7), U3.15 (2A1)
/ESP_ROMSEL_1: U1.22 (GPIO6), U3.17 (2A0)
/ESP_SPI_INT.CE: J3.6, U1.31 (GPIO5)
/ESP_SPI_INT.MISO: J3.2, U1.33 (GPIO19)
/ESP_SPI_INT.MOSI: J3.1, U1.39 (GPIO23)
/ESP_SPI_INT.OE: J3.7, U1.8 (GPIO33)
/ESP_SPI_INT.PL: J3.5, U1.9 (GPIO25)
/ESP_SPI_INT.SCK: J3.3, U1.32 (GPIO18)
/ESP_SPI_INT.STC: J3.4, U1.10 (GPIO26)
/ESP_WAIT_RESET: C1.1, IC3.13 (~R), R4.2, U1.18 (GPIO11)
/Glue Logic/CLR_Z80_HARDLOCK: IC3.1 (~R), IC4.3
/Glue Logic/PRE_Z80_HARDLOCK: IC1.4, IC3.4 (~S)
/Glue Logic/RIO CONTROL/PERMITTED_RIO_WR: IC5.11, U3.6 (1A2), U3.13 (2A2)
/Glue Logic/RIO CONTROL/RIO_IOD_ACCESS: IC6.3, IC8.5, U3.1 (1OE)
/Glue Logic/RIO CONTROL/RIO_IOD_CONFIG: IC6.1, IC8.2, U2.8
/Glue Logic/RIO CONTROL/Z80_ROM_ACCESS: IC5.4, IC7.8
/Glue Logic/RIO_IOD_DECODE: IC2.11, IC5.1, IC6.2, IC7.1, IC7.13, U3.8 (1A3)
/IORQ_FILTER_BITS: IC2.12, J8.38
/LOCAL_A0: CACHE1.9, J6.1, Z80_ADDRLOW1.18 (B0)
/LOCAL_A1: CACHE1.10, J6.2, Z80_ADDRLOW1.17 (B1)
/LOCAL_A2: CACHE1.11, J6.3, Z80_ADDRLOW1.16 (B2)
/LOCAL_A3: CACHE1.12, J6.4, Z80_ADDRLOW1.15 (B3)
/LOCAL_A4: CACHE1.13, J6.5, Z80_ADDRLOW1.14 (B4)
/LOCAL_A5: CACHE1.14, J6.6, Z80_ADDRLOW1.13 (B5)
/LOCAL_A6: CACHE1.15, J6.7, Z80_ADDRLOW1.12 (B6)
/LOCAL_A7: CACHE1.16, J6.8, Z80_ADDRLOW1.11 (B7)
/LOCAL_A8: CACHE1.17, J7.1, Z80_ADDRHIGH1.18 (B0)
/LOCAL_A9: CACHE1.18, J7.2, Z80_ADDRHIGH1.17 (B1)
/LOCAL_A10: CACHE1.19, J7.3, Z80_ADDRHIGH1.16 (B2)
/LOCAL_A11: CACHE1.20, J7.4, Z80_ADDRHIGH1.15 (B3)
/LOCAL_A12: CACHE1.21, J7.5, Z80_ADDRHIGH1.14 (B4)
/LOCAL_A13: CACHE1.22, J7.6, Z80_ADDRHIGH1.13 (B5)
/LOCAL_A14: CACHE1.23, IC5.9, J7.7, U3.4 (1A1), Z80_ADDRHIGH1.12 (B6)
/LOCAL_A15: CACHE1.24, IC5.10, J7.8, U3.2 (1A0), Z80_ADDRHIGH1.11 (B7)
/LOCAL_CONTROL.IORQ: IC6.13, LOCAL_CONTROL1.3
/LOCAL_CONTROL.MEMRQ: IC4.13, LOCAL_CONTROL1.4
/LOCAL_CONTROL.RD: IC4.10, LOCAL_CONTROL1.1
/LOCAL_CONTROL.WR: IC6.5, LOCAL_CONTROL1.2
/LOCAL_D0: CACHE1.1, J2.1, Z80-LOCAL_DATA1.18 (B0)
/LOCAL_D1: CACHE1.2, J2.2, Z80-LOCAL_DATA1.17 (B1)
/LOCAL_D2: CACHE1.3, J2.3, Z80-LOCAL_DATA1.16 (B2)
/LOCAL_D3: CACHE1.4, J2.4, Z80-LOCAL_DATA1.15 (B3)
/LOCAL_D4: CACHE1.5, J2.5, Z80-LOCAL_DATA1.14 (B4)
/LOCAL_D5: CACHE1.6, J2.6, Z80-LOCAL_DATA1.13 (B5)
/LOCAL_D6: CACHE1.7, J2.7, Z80-LOCAL_DATA1.12 (B6)
/LOCAL_D7: CACHE1.8, J2.8, Z80-LOCAL_DATA1.11 (B7)
/PERM_Z80_IORQ: IC2.4, IC4.12, RIO2.17
/RIO_CONTROL.A14: RIO2.4, RN1.2 (R1), U3.3 (2Y0), U3.18 (1Y0)
/RIO_CONTROL.A15: RIO2.3, RN1.3 (R2), U3.5 (2Y1), U3.16 (1Y1)
/RIO_CONTROL.A16: IC5.6, IC8.1, IC8.4, RIO2.2, U3.19 (2OE)
/RIO_CONTROL.CE: IC8.6, RIO2.6
/RIO_CONTROL.DATA_OE: IC8.3, RIO2.8
/RIO_CONTROL.OE: RIO2.7, RN1.5 (R4), U3.9 (2Y3), U3.12 (1Y3)
/RIO_CONTROL.WE: RIO2.5, RN1.4 (R3), U3.7 (2Y2), U3.14 (1Y2)
/WAIT_IO: IC1.9, RIO2.14
/Z80_A0: J8.18, RIO1.9, Z80_ADDRLOW1.2 (A0)
/Z80_A1: J8.17, RIO1.10, Z80_ADDRLOW1.3 (A1)
/Z80_A2: J8.16, RIO1.11, Z80_ADDRLOW1.4 (A2)
/Z80_A3: J8.15, RIO1.12, Z80_ADDRLOW1.5 (A3)
/Z80_A4: J8.14, RIO1.13, Z80_ADDRLOW1.6 (A4)
/Z80_A5: J8.13, RIO1.14, Z80_ADDRLOW1.7 (A5)
/Z80_A6: J8.12, RIO1.15, Z80_ADDRLOW1.8 (A6)
/Z80_A7: J8.11, RIO1.16, Z80_ADDRLOW1.9 (A7)
/Z80_A8: J8.26, RIO1.17, Z80_ADDRHIGH1.2 (A0)
/Z80_A9: J8.25, RIO1.18, Z80_ADDRHIGH1.3 (A1)
/Z80_A10: J8.24, RIO1.19, Z80_ADDRHIGH1.4 (A2)
/Z80_A11: J8.23, RIO1.20, Z80_ADDRHIGH1.5 (A3)
/Z80_A12: J8.22, RIO1.21, Z80_ADDRHIGH1.6 (A4)
/Z80_A13: J8.21, RIO1.22, Z80_ADDRHIGH1.7 (A5)
/Z80_A14: J8.20, RIO1.23, Z80_ADDRHIGH1.8 (A6)
/Z80_A15: J8.19, RIO1.24, Z80_ADDRHIGH1.9 (A7)
/Z80_BUS_CONTROL.Z80_ADD_DIR: IC2.3, IC7.12, IC8.10, Z80_ADDRHIGH1.1 (A->B), Z80_ADDRLOW1.1 (A->B)
/Z80_BUS_CONTROL.Z80_ADD_OE: IC8.8, Z80_ADDRHIGH1.19 (CE), Z80_ADDRLOW1.19 (CE)
/Z80_BUS_CONTROL.Z80_DATA_DIR: IC6.8, Z80-LOCAL_DATA1.1 (A->B)
/Z80_BUS_CONTROL.Z80_DATA_OE: IC7.11, Z80-LOCAL_DATA1.19 (CE)
/Z80_CONTROL.BUSACK: D4.1 (K), IC2.2, J5.8, J8.9
/Z80_CONTROL.BUSRQ: J5.5, J8.5
/Z80_CONTROL.IORQ: IC2.10, J5.3, J8.3
/Z80_CONTROL.MEMRQ: IC7.10, J5.4, J8.4
/Z80_CONTROL.NMI: J5.9, J8.7
/Z80_CONTROL.RD: IC4.9, IC7.2, J5.1, J8.1, U3.11 (2A3)
/Z80_CONTROL.RESET: D1.2 (A), J5.10, J8.10
/Z80_CONTROL.ROMCS: IC1.12, J5.7, J8.8
/Z80_CONTROL.WAIT: D2.1 (K), D5.2 (A), J5.6, J8.6
/Z80_CONTROL.WR: IC5.12, IC6.4, J5.2, J8.2
/Z80_D0: J8.34, RIO1.1, Z80-LOCAL_DATA1.2 (A0)
/Z80_D1: J8.33, RIO1.2, Z80-LOCAL_DATA1.3 (A1)
/Z80_D2: J8.32, RIO1.3, Z80-LOCAL_DATA1.4 (A2)
/Z80_D3: J8.31, RIO1.4, Z80-LOCAL_DATA1.5 (A3)
/Z80_D4: J8.30, RIO1.5, Z80-LOCAL_DATA1.6 (A4)
/Z80_D5: J8.29, RIO1.6, Z80-LOCAL_DATA1.7 (A5)
/Z80_D6: J8.28, RIO1.7, Z80-LOCAL_DATA1.8 (A6)
/Z80_D7: J8.27, RIO1.8, Z80-LOCAL_DATA1.9 (A7)
/Z80_HARDLOCK: CACHE2.7, IC3.5 (Q), U1.4 (GPIO39)
/Z80_HARDLOCK_RESET: D3.1 (K), IC1.5, RIO2.15
/Z80_HARDLOCK_SET: IC1.3, RIO2.16
/~ESP_HARDLOCK: IC1.2, J1.3
GND: C1.2, C2.2, C3.2, C4.2, C5.2, C6.2, CACHE2.14, EX_SPI1.6, IC1.14 (VCC), IC2.7 (GND), IC3.7 (GND), IC7.14 (VCC), IC8.12, IC8.13, J1.4, J8.40, J10.3, J10.4, R2.1, RIO2.18, U1.21 (GND), U1.34 (GND), U1.40 (GND), U2.7 (GND), U2.12, U2.13, U3.10 (GND), Z80-LOCAL_DATA1.10 (GND), Z80_ADDRHIGH1.10 (GND), Z80_ADDRLOW1.10 (GND)
unnamed: C2.1, IC4.1, R3.2
unnamed: D1.1 (K), U1.35 (GPIO21)
unnamed: D5.1 (K), IC3.8 (~Q)
unnamed: D6.1 (K), RN1.1 (common)
unnamed: IC1.6, IC4.2
unnamed: IC1.10, IC5.2
unnamed: IC2.8, IC2.13
unnamed: IC1.8, IC3.10 (~S)
unnamed: IC4.6, U2.1, U2.2
unnamed: IC5.3, IC8.9
unnamed: IC5.8, IC7.9
unnamed: IC6.10, IC7.3
unnamed: IC7.6, U2.5
unnamed: U2.3, U2.4
unnamed: U2.6, U2.9, U2.10

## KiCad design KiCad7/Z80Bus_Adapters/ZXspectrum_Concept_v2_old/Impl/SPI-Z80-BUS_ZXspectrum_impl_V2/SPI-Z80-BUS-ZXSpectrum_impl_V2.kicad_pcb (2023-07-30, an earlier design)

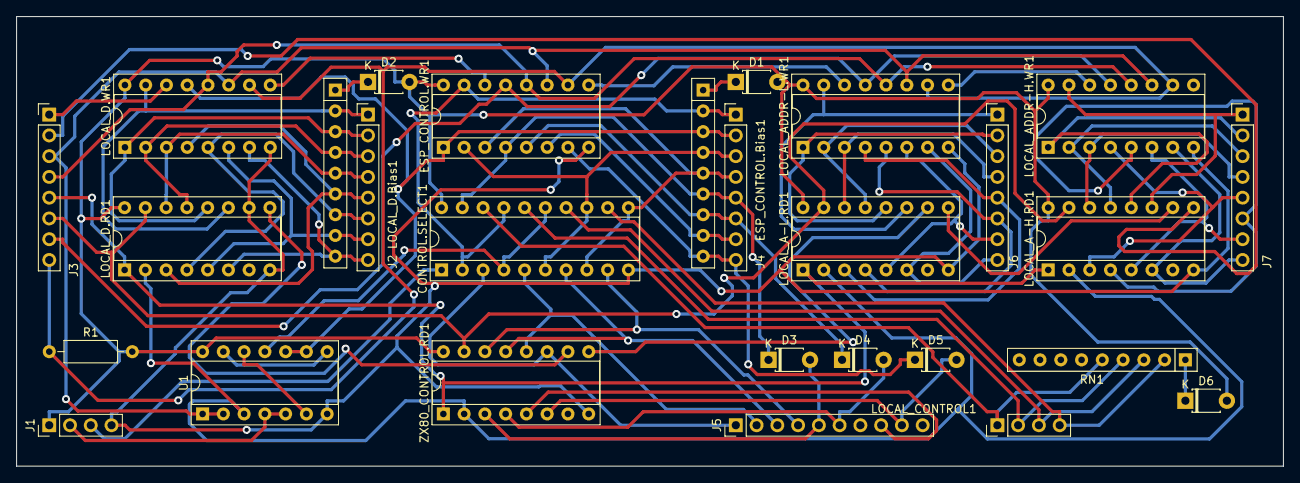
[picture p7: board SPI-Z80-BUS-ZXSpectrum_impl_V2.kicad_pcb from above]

Board: 2 copper layers, 155.0 x 55.0 mm, 28 parts (0 on the bottom side), 69 nets.

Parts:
CONTROL.SELECT1: 74HC244N; DIP-20_W7.62mm_Socket
D1, D2, D3, D4, D5, D6: 1N4148; D_T-1_P5.08mm_Horizontal
ESP_CONTROL.Bias1: 4609M-101-103LF; R_Array_SIP9
ESP_CONTROL.WR1: 74595N; DIP-16_W7.62mm_Socket
J1: PinHeader_2.54mm; PinHeader_1x04_P2.54mm_Vertical
J2: LOCAL_D; PinHeader_1x08_P2.54mm_Vertical
J3: ESP_SPI_INT; PinHeader_1x08_P2.54mm_Vertical
J4: ESP_CONTROL; PinHeader_1x08_P2.54mm_Vertical
J5: Z80_CONTROL; PinHeader_1x10_P2.54mm_Vertical
J6: LOCAL_A-L; PinHeader_1x08_P2.54mm_Vertical
J7: LOCAL_A-H; PinHeader_1x08_P2.54mm_Vertical
LOCAL_A-H.RD1: 74HC165N; DIP-16_W7.62mm_Socket
LOCAL_A-L.RD1: 74HC165N; DIP-16_W7.62mm_Socket
LOCAL_ADDR-H.WR1: 74595N; DIP-16_W7.62mm_Socket
LOCAL_ADDR-L.WR1: 74595N; DIP-16_W7.62mm_Socket
LOCAL_CONTROL1: LOCAL_CONTROL; PinHeader_1x04_P2.54mm_Vertical
LOCAL_D.Bias1: 4609M-101-103LF; R_Array_SIP9
LOCAL_D.RD1: 74HC165N; DIP-16_W7.62mm_Socket
LOCAL_D.WR1: 74595N; DIP-16_W7.62mm_Socket
R1: 22K; R_Axial_DIN0207_L6.3mm_D2.5mm_P10.16mm_Horizontal
RN1: LOCAL_CONTROL.Bias; R_Array_SIP9
U1: 74HC00; DIP-14_W7.62mm_Socket
ZX80_CONTROL.RD1: 74HC165N; DIP-16_W7.62mm_Socket

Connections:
+5V: CONTROL.SELECT1.20 (VCC), D1.2 (A), D2.2 (A), D6.2 (A), ESP_CONTROL.WR1.16 (VCC), J1.1, LOCAL_A-H.RD1.16 (VCC), LOCAL_A-L.RD1.16 (VCC), LOCAL_ADDR-H.WR1.16 (VCC), LOCAL_ADDR-L.WR1.16 (VCC), LOCAL_D.RD1.16 (VCC), LOCAL_D.WR1.16 (VCC), R1.2, U1.14 (VCC), ZX80_CONTROL.RD1.16 (VCC)
/SPI-Z80-BUS/!ESP_HARDLOCK: CONTROL.SELECT1.1 (1OE), J1.3
/SPI-Z80-BUS/ESP_CONTROL.BUSRQ: CONTROL.SELECT1.19 (2OE), D3.1 (K), ESP_CONTROL.Bias1.6 (R5), ESP_CONTROL.WR1.4 (QE), J4.5
/SPI-Z80-BUS/ESP_CONTROL.IORQ: CONTROL.SELECT1.6 (1A2), CONTROL.SELECT1.13 (2A2), ESP_CONTROL.Bias1.4 (R3), ESP_CONTROL.WR1.2 (QC), J4.3
/SPI-Z80-BUS/ESP_CONTROL.MEMRQ: CONTROL.SELECT1.8 (1A3), CONTROL.SELECT1.11 (2A3), ESP_CONTROL.Bias1.5 (R4), ESP_CONTROL.WR1.3 (QD), J4.4
/SPI-Z80-BUS/ESP_CONTROL.NMI: D5.1 (K), ESP_CONTROL.Bias1.9 (R8), ESP_CONTROL.WR1.7 (QH), J4.8
/SPI-Z80-BUS/ESP_CONTROL.RD: CONTROL.SELECT1.2 (1A0), CONTROL.SELECT1.17 (2A0), ESP_CONTROL.Bias1.2 (R1), ESP_CONTROL.WR1.15 (QA), J4.1
/SPI-Z80-BUS/ESP_CONTROL.ROMCS: ESP_CONTROL.Bias1.8 (R7), ESP_CONTROL.WR1.6 (QG), J4.7
/SPI-Z80-BUS/ESP_CONTROL.WAIT: D4.1 (K), ESP_CONTROL.Bias1.7 (R6), ESP_CONTROL.WR1.5 (QF), J4.6
/SPI-Z80-BUS/ESP_CONTROL.WR: ESP_CONTROL.Bias1.3 (R2), ESP_CONTROL.WR1.1 (QB), J4.2, LOCAL_D.WR1.13 (~OE), U1.9, U1.10
/SPI-Z80-BUS/ESP_PULSE: J1.2, U1.4, U1.5
/SPI-Z80-BUS/ESP_SPI_INT.CE: J3.6, LOCAL_A-H.RD1.15 (~CE), LOCAL_A-L.RD1.15 (~CE), LOCAL_D.RD1.15 (~CE), ZX80_CONTROL.RD1.15 (~CE)
/SPI-Z80-BUS/ESP_SPI_INT.MISO: J3.2, LOCAL_A-H.RD1.9 (Q7)
/SPI-Z80-BUS/ESP_SPI_INT.MOSI: J3.1, LOCAL_D.WR1.14 (SER)
/SPI-Z80-BUS/ESP_SPI_INT.MR: ESP_CONTROL.WR1.10 (~SRCLR), J3.8, LOCAL_ADDR-H.WR1.10 (~SRCLR), LOCAL_ADDR-L.WR1.10 (~SRCLR), LOCAL_D.WR1.10 (~SRCLR), R1.1
/SPI-Z80-BUS/ESP_SPI_INT.OE: ESP_CONTROL.WR1.13 (~OE), J3.7, LOCAL_ADDR-H.WR1.13 (~OE), LOCAL_ADDR-L.WR1.13 (~OE)
/SPI-Z80-BUS/ESP_SPI_INT.PL: J3.5, LOCAL_A-H.RD1.1 (~PL), LOCAL_A-L.RD1.1 (~PL), LOCAL_D.RD1.1 (~PL), ZX80_CONTROL.RD1.1 (~PL)
/SPI-Z80-BUS/ESP_SPI_INT.SCK: ESP_CONTROL.WR1.11 (SRCLK), J3.3, LOCAL_ADDR-H.WR1.11 (SRCLK), LOCAL_ADDR-L.WR1.11 (SRCLK), LOCAL_D.WR1.11 (SRCLK), U1.1, U1.2
/SPI-Z80-BUS/ESP_SPI_INT.STC: ESP_CONTROL.WR1.12 (RCLK), J3.4, LOCAL_ADDR-H.WR1.12 (RCLK), LOCAL_ADDR-L.WR1.12 (RCLK), LOCAL_D.WR1.12 (RCLK)
/SPI-Z80-BUS/LOCAL_A0: J6.1, LOCAL_A-L.RD1.11 (D0), LOCAL_ADDR-L.WR1.15 (QA)
/SPI-Z80-BUS/LOCAL_A1: J6.2, LOCAL_A-L.RD1.12 (D1), LOCAL_ADDR-L.WR1.1 (QB)
/SPI-Z80-BUS/LOCAL_A2: J6.3, LOCAL_A-L.RD1.13 (D2), LOCAL_ADDR-L.WR1.2 (QC)
/SPI-Z80-BUS/LOCAL_A3: J6.4, LOCAL_A-L.RD1.14 (D3), LOCAL_ADDR-L.WR1.3 (QD)
/SPI-Z80-BUS/LOCAL_A4: J6.5, LOCAL_A-L.RD1.3 (D4), LOCAL_ADDR-L.WR1.4 (QE)
/SPI-Z80-BUS/LOCAL_A5: J6.6, LOCAL_A-L.RD1.4 (D5), LOCAL_ADDR-L.WR1.5 (QF)
/SPI-Z80-BUS/LOCAL_A6: J6.7, LOCAL_A-L.RD1.5 (D6), LOCAL_ADDR-L.WR1.6 (QG)
/SPI-Z80-BUS/LOCAL_A7: J6.8, LOCAL_A-L.RD1.6 (D7), LOCAL_ADDR-L.WR1.7 (QH)
/SPI-Z80-BUS/LOCAL_A8: J7.1, LOCAL_A-H.RD1.11 (D0), LOCAL_ADDR-H.WR1.15 (QA)
/SPI-Z80-BUS/LOCAL_A9: J7.2, LOCAL_A-H.RD1.12 (D1), LOCAL_ADDR-H.WR1.1 (QB)
/SPI-Z80-BUS/LOCAL_A10: J7.3, LOCAL_A-H.RD1.13 (D2), LOCAL_ADDR-H.WR1.2 (QC)
/SPI-Z80-BUS/LOCAL_A11: J7.4, LOCAL_A-H.RD1.14 (D3), LOCAL_ADDR-H.WR1.3 (QD)
/SPI-Z80-BUS/LOCAL_A12: J7.5, LOCAL_A-H.RD1.3 (D4), LOCAL_ADDR-H.WR1.4 (QE)
/SPI-Z80-BUS/LOCAL_A13: J7.6, LOCAL_A-H.RD1.4 (D5), LOCAL_ADDR-H.WR1.5 (QF)
/SPI-Z80-BUS/LOCAL_A14: J7.7, LOCAL_A-H.RD1.5 (D6), LOCAL_ADDR-H.WR1.6 (QG)
/SPI-Z80-BUS/LOCAL_A15: J7.8, LOCAL_A-H.RD1.6 (D7), LOCAL_ADDR-H.WR1.7 (QH)
/SPI-Z80-BUS/LOCAL_CONTROL.IORQ: CONTROL.SELECT1.14 (1Y2), LOCAL_CONTROL1.3, RN1.3 (R2)
/SPI-Z80-BUS/LOCAL_CONTROL.MEMRQ: CONTROL.SELECT1.12 (1Y3), LOCAL_CONTROL1.4, RN1.2 (R1)
/SPI-Z80-BUS/LOCAL_CONTROL.RD: CONTROL.SELECT1.18 (1Y0), LOCAL_CONTROL1.1, RN1.5 (R4)
/SPI-Z80-BUS/LOCAL_CONTROL.WR: CONTROL.SELECT1.16 (1Y1), LOCAL_CONTROL1.2, RN1.4 (R3)
/SPI-Z80-BUS/LOCAL_D0: J2.1, LOCAL_D.Bias1.2 (R1), LOCAL_D.RD1.11 (D0), LOCAL_D.WR1.15 (QA)
/SPI-Z80-BUS/LOCAL_D1: J2.2, LOCAL_D.Bias1.3 (R2), LOCAL_D.RD1.12 (D1), LOCAL_D.WR1.1 (QB)
/SPI-Z80-BUS/LOCAL_D2: J2.3, LOCAL_D.Bias1.4 (R3), LOCAL_D.RD1.13 (D2), LOCAL_D.WR1.2 (QC)
/SPI-Z80-BUS/LOCAL_D3: J2.4, LOCAL_D.Bias1.5 (R4), LOCAL_D.RD1.14 (D3), LOCAL_D.WR1.3 (QD)
/SPI-Z80-BUS/LOCAL_D4: J2.5, LOCAL_D.Bias1.6 (R5), LOCAL_D.RD1.3 (D4), LOCAL_D.WR1.4 (QE)
/SPI-Z80-BUS/LOCAL_D5: J2.6, LOCAL_D.Bias1.7 (R6), LOCAL_D.RD1.4 (D5), LOCAL_D.WR1.5 (QF)
/SPI-Z80-BUS/LOCAL_D6: J2.7, LOCAL_D.Bias1.8 (R7), LOCAL_D.RD1.5 (D6), LOCAL_D.WR1.6 (QG)
/SPI-Z80-BUS/LOCAL_D7: J2.8, LOCAL_D.Bias1.9 (R8), LOCAL_D.RD1.6 (D7), LOCAL_D.WR1.7 (QH)
/SPI-Z80-BUS/SPI-Z80-BUS_read/ESP_SPI_INT.SCK: LOCAL_A-H.RD1.2 (CP), LOCAL_A-L.RD1.2 (CP), LOCAL_D.RD1.2 (CP), U1.3, ZX80_CONTROL.RD1.2 (CP)
/SPI-Z80-BUS/Z80_CONTROL.BUSACK: J5.8, ZX80_CONTROL.RD1.5 (D6)
/SPI-Z80-BUS/Z80_CONTROL.BUSRQ: D3.2 (A), J5.5, ZX80_CONTROL.RD1.3 (D4)
/SPI-Z80-BUS/Z80_CONTROL.IORQ: CONTROL.SELECT1.7 (2Y2), J5.3, ZX80_CONTROL.RD1.13 (D2)
/SPI-Z80-BUS/Z80_CONTROL.MEMRQ: CONTROL.SELECT1.9 (2Y3), J5.4, ZX80_CONTROL.RD1.14 (D3)
/SPI-Z80-BUS/Z80_CONTROL.NMI: D5.2 (A), J5.9, ZX80_CONTROL.RD1.6 (D7)
/SPI-Z80-BUS/Z80_CONTROL.RD: CONTROL.SELECT1.3 (2Y0), J5.1, ZX80_CONTROL.RD1.11 (D0)
/SPI-Z80-BUS/Z80_CONTROL.WAIT: D4.2 (A), J5.6, ZX80_CONTROL.RD1.4 (D5)
/SPI-Z80-BUS/Z80_CONTROL.WR: CONTROL.SELECT1.5 (2Y1), J5.2, ZX80_CONTROL.RD1.12 (D1)
GND: CONTROL.SELECT1.10 (GND), ESP_CONTROL.WR1.8 (GND), J1.4, LOCAL_A-H.RD1.8 (GND), LOCAL_A-L.RD1.8 (GND), LOCAL_ADDR-H.WR1.8 (GND), LOCAL_ADDR-L.WR1.8 (GND), LOCAL_D.RD1.8 (GND), LOCAL_D.RD1.10 (DS), LOCAL_D.WR1.8 (GND), U1.7 (GND), ZX80_CONTROL.RD1.8 (GND)
unnamed: CONTROL.SELECT1.4 (1A1), CONTROL.SELECT1.15 (2A1), U1.11
unnamed: D1.1 (K), ESP_CONTROL.Bias1.1 (common)
unnamed: D2.1 (K), LOCAL_D.Bias1.1 (common)
unnamed: D6.1 (K), RN1.1 (common)
unnamed: ESP_CONTROL.WR1.9 (QH'), LOCAL_ADDR-L.WR1.14 (SER)
unnamed: ESP_CONTROL.WR1.14 (SER), LOCAL_D.WR1.9 (QH')
unnamed: LOCAL_A-H.RD1.10 (DS), LOCAL_A-L.RD1.9 (Q7)
unnamed: LOCAL_A-L.RD1.10 (DS), ZX80_CONTROL.RD1.9 (Q7)
unnamed: LOCAL_ADDR-H.WR1.14 (SER), LOCAL_ADDR-L.WR1.9 (QH')
unnamed: LOCAL_D.RD1.9 (Q7), ZX80_CONTROL.RD1.10 (DS)
unnamed: U1.6, U1.12
unnamed: U1.8, U1.13

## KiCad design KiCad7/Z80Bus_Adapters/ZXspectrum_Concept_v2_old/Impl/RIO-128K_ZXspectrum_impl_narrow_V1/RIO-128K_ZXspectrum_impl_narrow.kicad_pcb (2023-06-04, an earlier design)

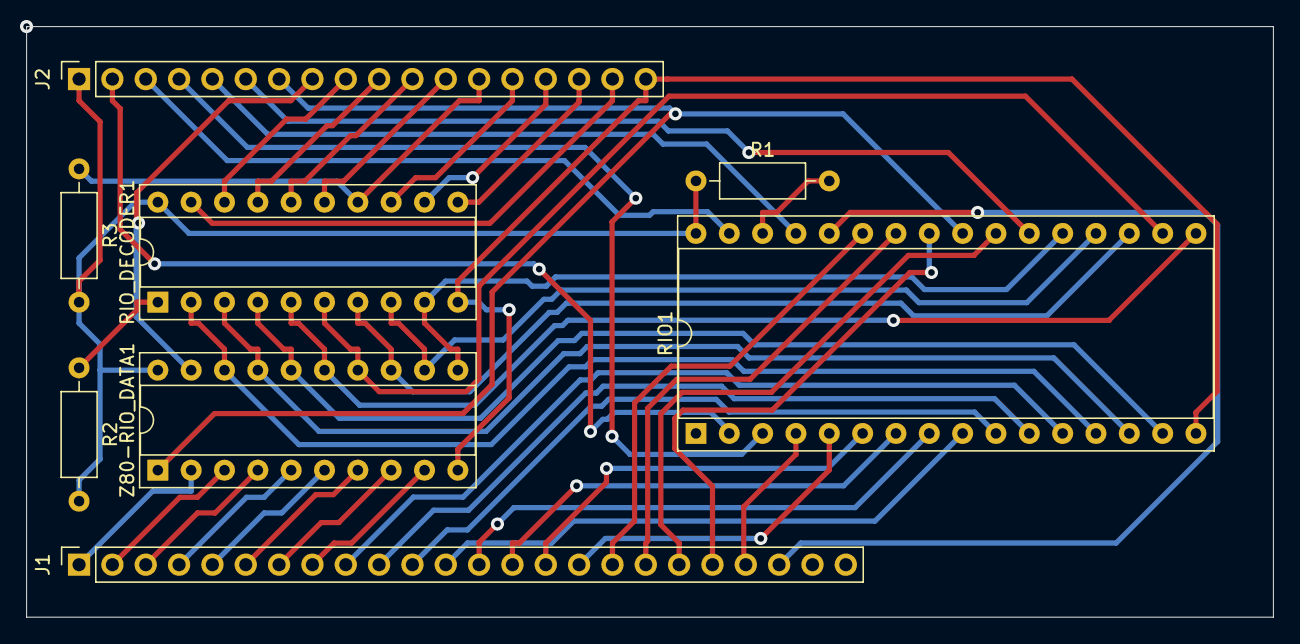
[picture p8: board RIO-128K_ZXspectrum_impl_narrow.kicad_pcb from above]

Board: 2 copper layers, 95.0 x 45.0 mm, 8 parts (0 on the bottom side), 50 nets.

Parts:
J1: Conn_01x24_Socket; PinSocket_1x24_P2.54mm_Vertical
J2: Conn_01x18_Socket; PinSocket_1x18_P2.54mm_Vertical
R1, R2, R3: 10K; R_Axial_DIN0207_L6.3mm_D2.5mm_P10.16mm_Horizontal
RIO1: AS6C1008-55PCN; DIP-32_W15.24mm_Socket
RIO_DECODER1: 74HC245N; DIP-20_W7.62mm_Socket
Z80-RIO_DATA1: 74HC245N; DIP-20_W7.62mm_Socket

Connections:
+5V: J2.1, R1.1, R2.2, R3.2, RIO1.32 (VCC), RIO_DECODER1.20 (VCC), Z80-RIO_DATA1.20 (VCC)
/RIO-128K_ZXspectrum/CACHE_DATASTATUS: J2.13, R3.1, RIO_DECODER1.14 (B4)
/RIO-128K_ZXspectrum/CACHE_SEL_0: J2.9, RIO_DECODER1.18 (B0)
/RIO-128K_ZXspectrum/CACHE_SEL_1: J2.10, RIO_DECODER1.17 (B1)
/RIO-128K_ZXspectrum/CACHE_SEL_2: J2.11, RIO_DECODER1.16 (B2)
/RIO-128K_ZXspectrum/CACHE_SEL_3: J2.12, RIO_DECODER1.15 (B3)
/RIO-128K_ZXspectrum/PERM_Z80_IORQ: J2.17, RIO_DECODER1.19 (CE)
/RIO-128K_ZXspectrum/RIO_CE2: R1.2, RIO1.30 (CE2#)
/RIO-128K_ZXspectrum/RIO_CONTROL.A14: J2.4, RIO1.3 (A14)
/RIO-128K_ZXspectrum/RIO_CONTROL.A15: J2.3, RIO1.31 (A15)
/RIO-128K_ZXspectrum/RIO_CONTROL.A16: J2.2, RIO1.2 (A16)
/RIO-128K_ZXspectrum/RIO_CONTROL.CE: J2.6, RIO1.22 (CE#)
/RIO-128K_ZXspectrum/RIO_CONTROL.OE: J2.7, RIO1.24 (OE#), Z80-RIO_DATA1.1 (A->B)
/RIO-128K_ZXspectrum/RIO_CONTROL.ROM_RDY: J2.8, Z80-RIO_DATA1.19 (CE)
/RIO-128K_ZXspectrum/RIO_CONTROL.WE: J2.5, RIO1.29 (WE#)
/RIO-128K_ZXspectrum/ROM_D0: RIO1.13 (DQ0), RIO_DECODER1.2 (A0), Z80-RIO_DATA1.18 (B0)
/RIO-128K_ZXspectrum/ROM_D1: RIO1.14 (DQ1), RIO_DECODER1.3 (A1), Z80-RIO_DATA1.17 (B1)
/RIO-128K_ZXspectrum/ROM_D2: RIO1.15 (DQ2), RIO_DECODER1.4 (A2), Z80-RIO_DATA1.16 (B2)
/RIO-128K_ZXspectrum/ROM_D3: RIO1.17 (DQ3), RIO_DECODER1.5 (A3), Z80-RIO_DATA1.15 (B3)
/RIO-128K_ZXspectrum/ROM_D4: RIO1.18 (DQ4), RIO_DECODER1.6 (A4), Z80-RIO_DATA1.14 (B4)
/RIO-128K_ZXspectrum/ROM_D5: RIO1.19 (DQ5), RIO_DECODER1.7 (A5), Z80-RIO_DATA1.13 (B5)
/RIO-128K_ZXspectrum/ROM_D6: RIO1.20 (DQ6), RIO_DECODER1.8 (A6), Z80-RIO_DATA1.12 (B6)
/RIO-128K_ZXspectrum/ROM_D7: RIO1.21 (DQ7), RIO_DECODER1.9 (A7), Z80-RIO_DATA1.11 (B7)
/RIO-128K_ZXspectrum/WAIT_IO: J2.14, RIO_DECODER1.13 (B5)
/RIO-128K_ZXspectrum/Z80_A0: J1.9, RIO1.12 (A0)
/RIO-128K_ZXspectrum/Z80_A1: J1.10, RIO1.11 (A1)
/RIO-128K_ZXspectrum/Z80_A2: J1.11, RIO1.10 (A2)
/RIO-128K_ZXspectrum/Z80_A3: J1.12, RIO1.9 (A3)
/RIO-128K_ZXspectrum/Z80_A4: J1.13, RIO1.8 (A4)
/RIO-128K_ZXspectrum/Z80_A5: J1.14, RIO1.7 (A5)
/RIO-128K_ZXspectrum/Z80_A6: J1.15, RIO1.6 (A6)
/RIO-128K_ZXspectrum/Z80_A7: J1.16, RIO1.5 (A7)
/RIO-128K_ZXspectrum/Z80_A8: J1.17, RIO1.27 (A8)
/RIO-128K_ZXspectrum/Z80_A9: J1.18, RIO1.26 (A9)
/RIO-128K_ZXspectrum/Z80_A10: J1.19, RIO1.23 (A10)
/RIO-128K_ZXspectrum/Z80_A11: J1.20, RIO1.25 (A11)
/RIO-128K_ZXspectrum/Z80_A12: J1.21, RIO1.4 (A12)
/RIO-128K_ZXspectrum/Z80_A13: J1.22, RIO1.28 (A13)
/RIO-128K_ZXspectrum/Z80_D0: J1.1, Z80-RIO_DATA1.2 (A0)
/RIO-128K_ZXspectrum/Z80_D1: J1.2, Z80-RIO_DATA1.3 (A1)
/RIO-128K_ZXspectrum/Z80_D2: J1.3, Z80-RIO_DATA1.4 (A2)
/RIO-128K_ZXspectrum/Z80_D3: J1.4, Z80-RIO_DATA1.5 (A3)
/RIO-128K_ZXspectrum/Z80_D4: J1.5, Z80-RIO_DATA1.6 (A4)
/RIO-128K_ZXspectrum/Z80_D5: J1.6, Z80-RIO_DATA1.7 (A5)
/RIO-128K_ZXspectrum/Z80_D6: J1.7, Z80-RIO_DATA1.8 (A6)
/RIO-128K_ZXspectrum/Z80_D7: J1.8, Z80-RIO_DATA1.9 (A7)
/RIO-128K_ZXspectrum/Z80_HARDLOCK_RESET: J2.15, RIO_DECODER1.12 (B6)
/RIO-128K_ZXspectrum/Z80_HARDLOCK_SET: J2.16, RIO_DECODER1.11 (B7)
GND: J2.18, RIO1.16 (VSS), RIO_DECODER1.10 (GND), Z80-RIO_DATA1.10 (GND)
unnamed: R2.1, RIO_DECODER1.1 (A->B)

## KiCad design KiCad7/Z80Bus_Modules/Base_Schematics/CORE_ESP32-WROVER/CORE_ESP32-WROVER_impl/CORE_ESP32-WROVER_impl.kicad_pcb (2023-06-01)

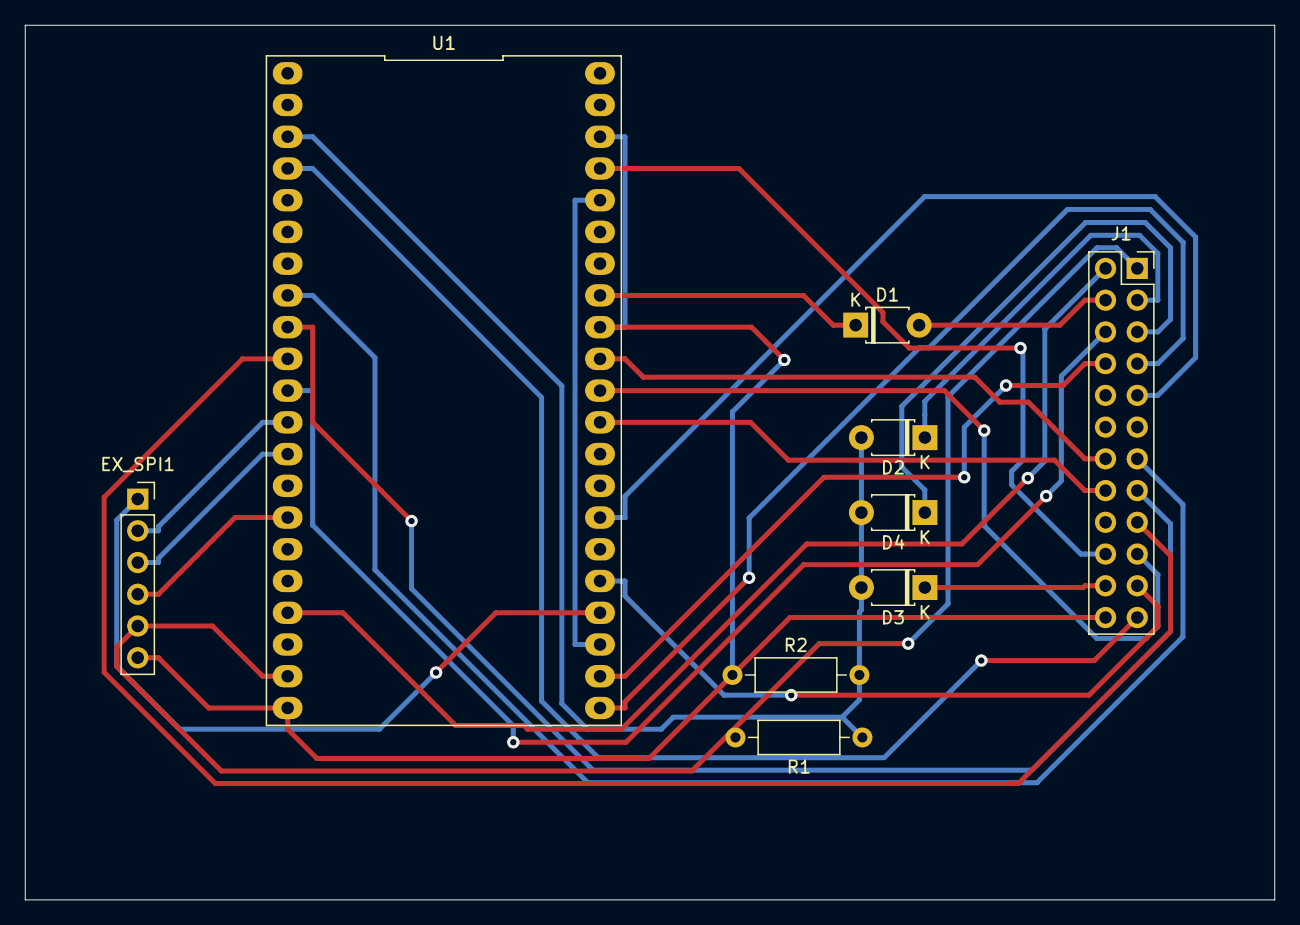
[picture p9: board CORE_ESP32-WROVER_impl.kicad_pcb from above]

Board: 2 copper layers, 100.0 x 70.0 mm, 9 parts (0 on the bottom side), 27 nets.

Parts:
D1, D2, D3, D4: 1N4148; D_T-1_P5.08mm_Horizontal
EX_SPI1: PinSocket_2.54mm; PinSocket_1x06_P2.54mm_Vertical
J1: Conn_02x12_Counter_Clockwise; PinSocket_2x12_P2.54mm_Vertical
R1, R2: 22K; R_Axial_DIN0207_L6.3mm_D2.5mm_P10.16mm_Horizontal
U1: FREENOVE_ESP32-WROVER-DEV

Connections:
+5V: EX_SPI1.5, J1.1, R1.2, U1.20 (+5V)
/CORE_ESP32-WROVER/ESP_HARDLOCK: J1.21, U1.26 (GPIO2)
/CORE_ESP32-WROVER/ESP_INT: D2.2 (A), D3.2 (A), D4.2 (A), R1.1, R2.2, U1.3 (GPIO36)
/CORE_ESP32-WROVER/ESP_PULSE: J1.6, U1.11 (GPIO27)
/CORE_ESP32-WROVER/ESP_ROMSEL_0: J1.8, U1.23 (GPIO7)
/CORE_ESP32-WROVER/ESP_ROMSEL_1: J1.7, U1.22 (GPIO6)
/CORE_ESP32-WROVER/ESP_ROM_WR_PROTECT: J1.9, U1.28 (GPIO4)
/CORE_ESP32-WROVER/ESP_SPI_INT.CE: J1.16, U1.31 (GPIO5)
/CORE_ESP32-WROVER/ESP_SPI_INT.MISO: J1.14, U1.33 (GPIO19)
/CORE_ESP32-WROVER/ESP_SPI_INT.MOSI: J1.20, U1.39 (GPIO23)
/CORE_ESP32-WROVER/ESP_SPI_INT.OE: J1.13, U1.8 (GPIO33)
/CORE_ESP32-WROVER/ESP_SPI_INT.PL: J1.15, U1.9 (GPIO25)
/CORE_ESP32-WROVER/ESP_SPI_INT.SCK: J1.19, U1.32 (GPIO18)
/CORE_ESP32-WROVER/ESP_SPI_INT.STC: J1.17, U1.10 (GPIO26)
/CORE_ESP32-WROVER/ESP_WAIT_RESET: J1.2, U1.18 (GPIO11)
/CORE_ESP32-WROVER/EX_MISO: EX_SPI1.3, U1.13 (GPIO12)
/CORE_ESP32-WROVER/EX_MOSI: EX_SPI1.4, U1.15 (GPIO13)
/CORE_ESP32-WROVER/EX_SCK: EX_SPI1.2, U1.12 (GPIO14)
/CORE_ESP32-WROVER/EX_SS: EX_SPI1.1, U1.25 (GPIO8)
/CORE_ESP32-WROVER/SD_CARD_SS: U1.24 (GPIO15), U1.38 (GPIO22)
/CORE_ESP32-WROVER/Z80_CONTROL.BUSACK: D4.1 (K), J1.5
/CORE_ESP32-WROVER/Z80_CONTROL.RESET: D1.2 (A), J1.4
/CORE_ESP32-WROVER/Z80_CONTROL.WAIT: D2.1 (K), J1.3
/CORE_ESP32-WROVER/Z80_HARDLOCK: J1.23, U1.4 (GPIO39)
/CORE_ESP32-WROVER/Z80_HARDLOCK_RESET: D3.1 (K), J1.22
GND: EX_SPI1.6, J1.24, R2.1, U1.21 (GND), U1.34 (GND), U1.40 (GND)
unnamed: D1.1 (K), U1.35 (GPIO21)

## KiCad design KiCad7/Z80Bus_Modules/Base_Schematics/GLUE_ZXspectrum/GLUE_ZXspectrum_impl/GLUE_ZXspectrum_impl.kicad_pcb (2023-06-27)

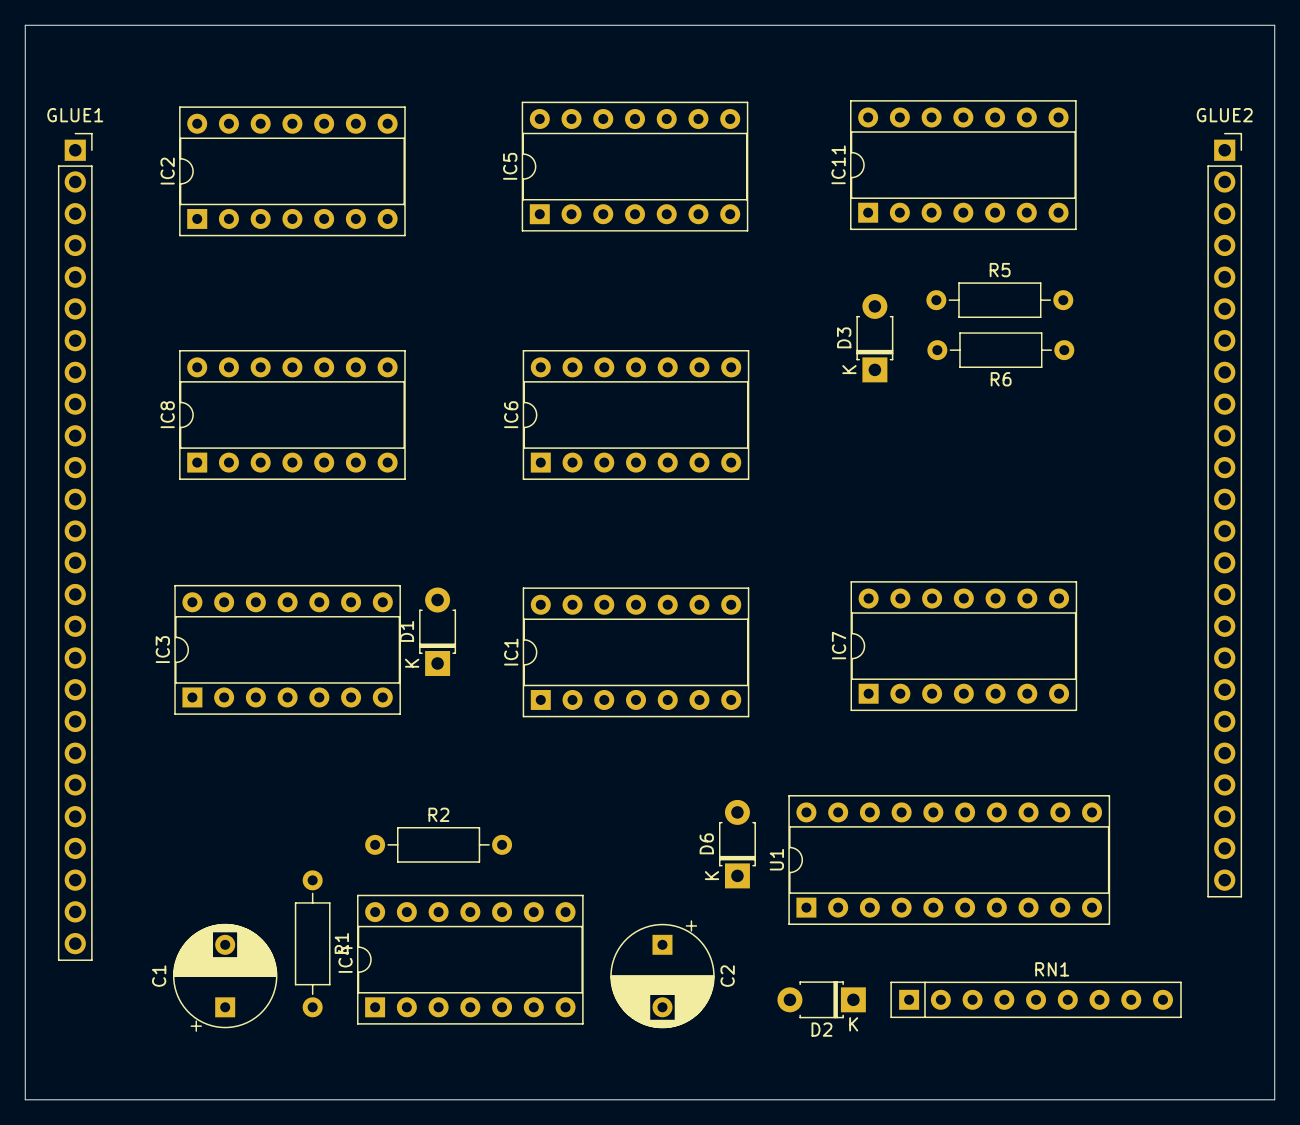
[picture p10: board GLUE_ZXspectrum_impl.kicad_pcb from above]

Board: 2 copper layers, 100.0 x 86.0 mm, 23 parts (0 on the bottom side), 72 nets, no tracks yet.

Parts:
C1, C2: 10UF; CP_Radial_D8.0mm_P5.00mm
D1, D2, D3, D6: 1N4148; D_T-1_P5.08mm_Horizontal
GLUE1: Conn_01x26_Socket; PinSocket_1x26_P2.54mm_Vertical
GLUE2: Conn_01x24_Socket; PinSocket_1x24_P2.54mm_Vertical
IC1: 7404N; DIP-14_W7.62mm_Socket
IC2, IC5, IC7: 74HC32N; DIP-14_W7.62mm_Socket
IC3: 7474N; DIP-14_W7.62mm_Socket
IC4, IC6, IC8, IC11: 74HC08N; DIP-14_W7.62mm_Socket
R1, R2: 22K; R_Axial_DIN0207_L6.3mm_D2.5mm_P10.16mm_Horizontal
R5, R6: 10K; R_Axial_DIN0207_L6.3mm_D2.5mm_P10.16mm_Horizontal
RN1: 4609M-101-103LF; R_Array_SIP9
U1: 74HC244N; DIP-20_W7.62mm_Socket

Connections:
+5V: D6.2 (A), GLUE1.1, IC1.14 (VCC), IC2.14 (VCC), IC3.14 (VCC), IC4.14 (VCC), IC5.14 (VCC), IC6.14 (VCC), IC7.14 (VCC), IC8.7 (GND), IC11.7 (GND), R1.1, R2.1, R5.2, R6.1, U1.20 (VCC)
/!ESP_HARDLOCK: GLUE1.21, IC1.2
/!Z80_HARDLOCK: GLUE1.23, IC3.6 (~Q)
/CACHE_CONTROL.A16: GLUE2.14, IC8.3
/CACHE_CONTROL.CS: GLUE2.17, IC8.11
/CACHE_CONTROL.DATASTATUS+PERM_Z80_IORQ: GLUE2.13, IC2.6
/CACHE_CONTROL.OE: GLUE2.16, IC8.8
/CACHE_CONTROL.WE: GLUE2.15, IC8.6
/CACHE_DATASTATUS: GLUE2.5, IC1.11, IC2.5, IC8.1
/ESP_CONTROL.BUSRQ: GLUE1.15, IC7.10
/ESP_CONTROL.IORQ: GLUE1.13, IC6.5
/ESP_CONTROL.MEMRQ: GLUE1.14, IC6.4, IC11.4
/ESP_CONTROL.ROMCS: GLUE1.16, IC5.9
/ESP_CONTROL.WR: GLUE1.12, IC5.4
/ESP_HARDLOCK: GLUE1.20, IC1.1, IC2.2, IC2.9
/ESP_ROMSEL_0: GLUE1.18, U1.15 (2A1)
/ESP_ROMSEL_1: GLUE1.19, U1.17 (2A0)
/ESP_ROM_WR_PROTECT: GLUE1.17, IC7.13
/ESP_WAIT_RESET: C2.1, GLUE2.6, IC3.13 (~R), R2.2
/GLUE_ZXspectrum/CLR_Z80_HARDLOCK: IC3.1 (~R), IC4.3
/GLUE_ZXspectrum/ESP_IOD_CONFIG: IC4.5, IC4.12, IC5.1, IC5.13, IC7.8, IC11.5
/GLUE_ZXspectrum/PRE_Z80_HARDLOCK: IC2.3, IC3.4 (~S)
/GLUE_ZXspectrum/RIO CONTROL/ROM_WR_PROTECT+Z80_WR: IC7.11, U1.13 (2A2)
/GLUE_ZXspectrum/RIO CONTROL/Z80_RD+ESP_IOD_CONFIG+PERM_Z80_IORQ: IC6.3, U1.8 (1A3)
/GLUE_ZXspectrum/RIO CONTROL/Z80_WR+ESP_IOD_CONFIG: IC5.3, U1.6 (1A2)
/GLUE_ZXspectrum/Z80 BUS CONTROL/!CACHE_DATASTATUS: IC1.10, IC7.2
/GLUE_ZXspectrum/Z80 BUS CONTROL/Z80_ADD_CONNECT: D2.2 (A), IC11.2, R5.1
/GLUE_ZXspectrum/Z80 BUS CONTROL/Z80_DATA_CONNECT: D3.2 (A), IC5.5, IC11.13, R6.2
/IORQ_FILTER_BIT: GLUE2.1, IC2.12
/LOCAL_CONTROL.IORQ: GLUE1.10, IC8.2
/LOCAL_CONTROL.MEMRQ: GLUE1.11, IC8.13
/LOCAL_CONTROL.RD: GLUE1.8, IC8.10
/LOCAL_CONTROL.WR: GLUE1.9, IC8.5
/PERM_Z80_IORQ: GLUE1.24, IC2.4, IC2.11, IC4.4, IC6.1, IC7.1, IC7.5, IC8.12, IC11.12
/RIO_CONTROL.A14: GLUE2.20, RN1.2 (R1), U1.3 (2Y0), U1.18 (1Y0)
/RIO_CONTROL.A15: GLUE2.19, RN1.3 (R2), U1.5 (2Y1), U1.16 (1Y1)
/RIO_CONTROL.A16: GLUE2.18, IC4.6, IC4.10, U1.1 (1OE)
/RIO_CONTROL.CE: GLUE2.23, IC4.8
/RIO_CONTROL.OE: GLUE2.22, RN1.5 (R4), U1.9 (2Y3), U1.12 (1Y3)
/RIO_CONTROL.ROM_RDY: GLUE2.24, IC4.13, IC5.8, U1.19 (2OE)
/RIO_CONTROL.WE: GLUE2.21, RN1.4 (R3), U1.7 (2Y2), U1.14 (1Y2)
/WAIT_IO: GLUE2.4, IC1.9
/Z80_A14: GLUE2.8, U1.4 (1A1)
/Z80_A15: GLUE2.7, U1.2 (1A0)
/Z80_BUS_CONTROL.Z80_ADD_DIR: GLUE2.10, IC11.6
/Z80_BUS_CONTROL.Z80_ADD_OE: GLUE2.9, IC11.3
/Z80_BUS_CONTROL.Z80_DATA_DIR: GLUE2.11, IC11.8
/Z80_BUS_CONTROL.Z80_DATA_OE: GLUE2.12, IC11.11
/Z80_CONTROL.BUSRQ: D2.1 (K), D3.1 (K), GLUE1.6
/Z80_CONTROL.IORQ: GLUE1.4, IC2.10
/Z80_CONTROL.MEMRQ: GLUE1.5, IC5.10
/Z80_CONTROL.RD: GLUE1.2, IC5.12, IC7.4, IC8.9, U1.11 (2A3)
/Z80_CONTROL.WAIT: D1.2 (A), GLUE1.7
/Z80_CONTROL.WR: GLUE1.3, IC5.2, IC7.12, IC8.4
/Z80_HARDLOCK: GLUE1.22, IC3.5 (Q)
/Z80_HARDLOCK_RESET: GLUE2.2, IC1.5
/Z80_HARDLOCK_SET: GLUE2.3, IC1.3
GND: C1.2, C2.2, GLUE1.26, IC1.7 (GND), IC2.7 (GND), IC3.7 (GND), IC4.7 (GND), IC5.7 (GND), IC6.7 (GND), IC6.9, IC6.10, IC6.12, IC6.13, IC7.7 (GND), IC8.14 (VCC), IC11.14 (VCC), U1.10 (GND)
unnamed: C1.1, IC4.1, R1.2
unnamed: D1.1 (K), IC3.8 (~Q)
unnamed: D6.1 (K), RN1.1 (common)
unnamed: IC1.4, IC2.1
unnamed: IC1.6, IC4.2
unnamed: IC1.12, IC7.9
unnamed: IC1.13, IC6.6
unnamed: IC2.8, IC2.13
unnamed: IC1.8, IC3.10 (~S)
unnamed: IC4.9, IC4.11
unnamed: IC5.11, IC6.2
unnamed: IC7.3, IC11.1
unnamed: IC5.6, IC11.9
unnamed: IC7.6, IC11.10

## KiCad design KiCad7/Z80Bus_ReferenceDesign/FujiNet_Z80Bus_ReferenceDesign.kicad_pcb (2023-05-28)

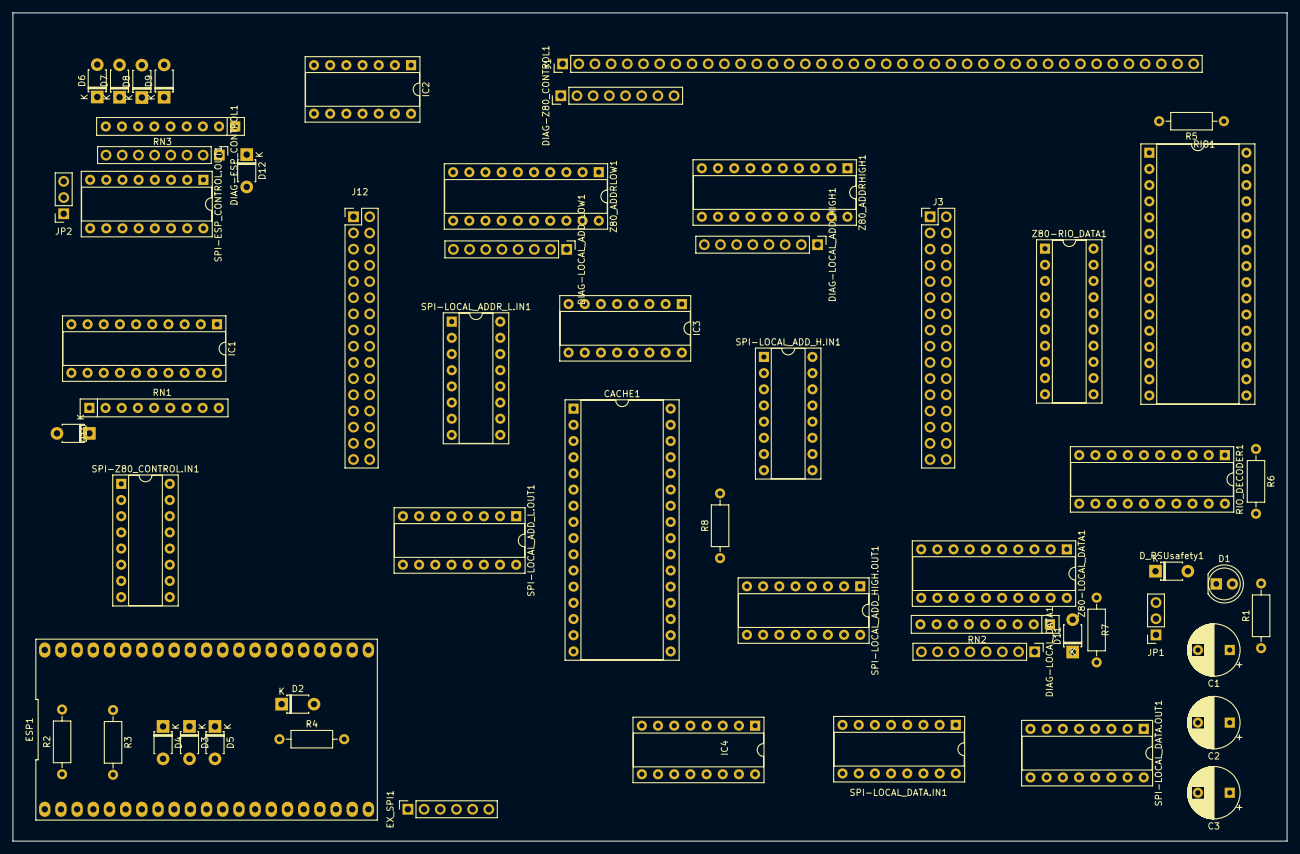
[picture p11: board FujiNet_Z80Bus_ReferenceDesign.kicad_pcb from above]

Board: 2 copper layers, 200.0 x 130.0 mm, 58 parts (0 on the bottom side), 142 nets, no tracks yet.

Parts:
C1: 10 uf; CP_Radial_D8.0mm_P5.00mm
C2, C3: .1 uf; CP_Radial_D8.0mm_P5.00mm
CACHE1: AS6C1008-55PCN; DIP-32_W15.24mm_Socket
D1: POWER_LED; LED_D5.0mm
D2, D3, D4, D5, D6, D7, D8, D9, D10, D11, D12: 1N4148; D_T-1_P5.08mm_Horizontal
DIAG-ESP_CONTROL1: PinHeader_2.54mm; PinHeader_1x08_P2.54mm_Vertical
DIAG-LOCAL_ADD_HIGH1: PinHeader_2.54mm; PinHeader_1x08_P2.54mm_Vertical
DIAG-LOCAL_ADD_LOW1: PinHeader_2.54mm; PinHeader_1x08_P2.54mm_Vertical
DIAG-LOCAL_DATA1: PinHeader_2.54mm; PinHeader_1x08_P2.54mm_Vertical
DIAG-Z80_CONTROL1: PinHeader_2.54mm; PinHeader_1x08_P2.54mm_Vertical
D_PSUsafety1: 1N4148; D_T-1_P5.08mm_Horizontal
ESP1: FREENOVE_ESP32-WROVER-DEV
EX_SPI1: PinSocket_2.54mm; PinSocket_1x06_P2.54mm_Vertical
IC1: 74HC244N; DIP-20_W7.62mm_Socket
IC2: 74HC32N; DIP-14_W7.62mm_Socket
IC3, IC4: 74HC590N; DIP-16_W7.62mm_Socket
J1: DIAG-HOST_SYSTEM_BUS; PinHeader_1x40_P2.54mm_Vertical
J3, J12: Conn_02x12_Odd_Even; PinHeader_2x16_P2.54mm_Vertical
JP1: PINHD-POWER/RESET; PinSocket_1x03_P2.54mm_Vertical
JP2: PINHD-ADDR_FILTER; PinSocket_1x03_P2.54mm_Vertical
R1: 1K; R_Axial_DIN0207_L6.3mm_D2.5mm_P10.16mm_Horizontal
R2, R3, R4: 22K; R_Axial_DIN0207_L6.3mm_D2.5mm_P10.16mm_Horizontal
R5, R6, R7, R8: 10K; R_Axial_DIN0207_L6.3mm_D2.5mm_P10.16mm_Horizontal
RIO1: AS6C1008-55PCN; DIP-32_W15.24mm_Socket
RIO_DECODER1: 74HC245N; DIP-20_W7.62mm_Socket
RN1: LOCAL_CONTROL_BIAS; R_Array_SIP9
RN2, RN3: 4609M-101-103LF; R_Array_SIP9
SPI-ESP_CONTROL.OUT1: 74595N; DIP-16_W7.62mm_Socket
SPI-LOCAL_ADDR_L.IN1: 74HC165N; DIP-16_W7.62mm_Socket
SPI-LOCAL_ADD_H.IN1: 74HC165N; DIP-16_W7.62mm_Socket
SPI-LOCAL_ADD_HIGH.OUT1: 74595N; DIP-16_W7.62mm_Socket
SPI-LOCAL_ADD_L.OUT1: 74595N; DIP-16_W7.62mm_Socket
SPI-LOCAL_DATA.IN1: 74HC165N; DIP-16_W7.62mm_Socket
SPI-LOCAL_DATA.OUT1: 74595N; DIP-16_W7.62mm_Socket
SPI-Z80_CONTROL.IN1: 74HC165N; DIP-16_W7.62mm_Socket
Z80-LOCAL_DATA1, Z80-RIO_DATA1, Z80_ADDRHIGH1, Z80_ADDRLOW1: 74HC245N; DIP-20_W7.62mm_Socket

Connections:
+5V: C1.1, C2.1, C3.1, CACHE1.32 (VCC), D10.2 (A), D11.2 (A), D12.2 (A), D_PSUsafety1.2 (A), ESP1.20 (+5V), EX_SPI1.5, IC1.20 (VCC), IC2.14 (VCC), IC3.16 (VCC), IC4.16 (VCC), J12.21, R1.1, R2.2, R4.1, R5.1, R6.2, R7.2, R8.2, RIO1.32 (VCC), RIO_DECODER1.20 (VCC), SPI-ESP_CONTROL.OUT1.16 (VCC), SPI-LOCAL_ADDR_L.IN1.16 (VCC), SPI-LOCAL_ADD_H.IN1.16 (VCC), SPI-LOCAL_ADD_HIGH.OUT1.16 (VCC), SPI-LOCAL_ADD_L.OUT1.16 (VCC), SPI-LOCAL_DATA.IN1.16 (VCC), SPI-LOCAL_DATA.OUT1.16 (VCC), SPI-Z80_CONTROL.IN1.16 (VCC), Z80-LOCAL_DATA1.20 (VCC), Z80-RIO_DATA1.20 (VCC), Z80_ADDRHIGH1.20 (VCC), Z80_ADDRLOW1.20 (VCC)
/!ESP_HARDLOCK: IC1.19 (2OE), J12.20
/CACHE_CONTROL.A16: CACHE1.2 (A16), J3.12
/CACHE_CONTROL.CS: CACHE1.22 (CE#), J3.18
/CACHE_CONTROL.DATASTATUS+PERM_Z80_IORQ: IC3.11 (CPC), IC3.13 (CPR), J3.10
/CACHE_CONTROL.OE: CACHE1.24 (OE#), J3.16
/CACHE_CONTROL.WE: CACHE1.29 (WE#), J3.14
/CACHE_DATASTATUS: IC3.12 (~CE), IC3.14 (~OE), IC4.12 (~CE), IC4.14 (~OE), J3.9, R7.1, RIO_DECODER1.14 (B4)
/CACHE_SEL_0: CACHE1.4 (A12), RIO_DECODER1.18 (B0)
/CACHE_SEL_1: CACHE1.28 (A13), RIO_DECODER1.17 (B1)
/CACHE_SEL_2: CACHE1.3 (A14), RIO_DECODER1.16 (B2)
/CACHE_SEL_3: CACHE1.31 (A15), RIO_DECODER1.15 (B3)
/CORE_ESP32-WROVER/ESP_INT: D3.2 (A), D4.2 (A), D5.2 (A), ESP1.3 (GPIO36), R2.1, R3.2
/CORE_ESP32-WROVER/ESP_PULSE: ESP1.11 (GPIO27), IC2.1
/CORE_ESP32-WROVER/ESP_SPI_INT.CE: ESP1.31 (GPIO5), SPI-LOCAL_ADDR_L.IN1.15 (~CE), SPI-LOCAL_ADD_H.IN1.15 (~CE), SPI-LOCAL_DATA.IN1.15 (~CE), SPI-Z80_CONTROL.IN1.15 (~CE)
/CORE_ESP32-WROVER/ESP_SPI_INT.MISO: ESP1.33 (GPIO19), SPI-LOCAL_ADD_H.IN1.7 (~Q7)
/CORE_ESP32-WROVER/ESP_SPI_INT.MOSI: ESP1.39 (GPIO23), SPI-LOCAL_DATA.OUT1.14 (SER)
/CORE_ESP32-WROVER/ESP_SPI_INT.MR: R4.2, SPI-ESP_CONTROL.OUT1.10 (~SRCLR), SPI-LOCAL_ADD_HIGH.OUT1.10 (~SRCLR), SPI-LOCAL_ADD_L.OUT1.10 (~SRCLR), SPI-LOCAL_DATA.OUT1.10 (~SRCLR)
/CORE_ESP32-WROVER/ESP_SPI_INT.OE: ESP1.8 (GPIO33), SPI-ESP_CONTROL.OUT1.13 (~OE), SPI-LOCAL_ADD_HIGH.OUT1.13 (~OE), SPI-LOCAL_ADD_L.OUT1.13 (~OE)
/CORE_ESP32-WROVER/ESP_SPI_INT.PL: ESP1.9 (GPIO25), SPI-LOCAL_ADDR_L.IN1.1 (~PL), SPI-LOCAL_ADD_H.IN1.1 (~PL), SPI-LOCAL_DATA.IN1.1 (~PL), SPI-Z80_CONTROL.IN1.1 (~PL)
/CORE_ESP32-WROVER/ESP_SPI_INT.SCK: ESP1.32 (GPIO18), SPI-ESP_CONTROL.OUT1.11 (SRCLK), SPI-LOCAL_ADDR_L.IN1.2 (CP), SPI-LOCAL_ADD_H.IN1.2 (CP), SPI-LOCAL_ADD_HIGH.OUT1.11 (SRCLK), SPI-LOCAL_ADD_L.OUT1.11 (SRCLK), SPI-LOCAL_DATA.IN1.2 (CP), SPI-LOCAL_DATA.OUT1.11 (SRCLK), SPI-Z80_CONTROL.IN1.2 (CP)
/CORE_ESP32-WROVER/ESP_SPI_INT.STC: ESP1.10 (GPIO26), SPI-ESP_CONTROL.OUT1.12 (RCLK), SPI-LOCAL_ADD_HIGH.OUT1.12 (RCLK), SPI-LOCAL_ADD_L.OUT1.12 (RCLK), SPI-LOCAL_DATA.OUT1.12 (RCLK)
/CORE_ESP32-WROVER/EX_MISO: ESP1.13 (GPIO12), EX_SPI1.3
/CORE_ESP32-WROVER/EX_MOSI: ESP1.15 (GPIO13), EX_SPI1.4
/CORE_ESP32-WROVER/EX_SCK: ESP1.12 (GPIO14), EX_SPI1.2
/CORE_ESP32-WROVER/EX_SS: ESP1.25 (GPIO8), EX_SPI1.1
/CORE_ESP32-WROVER/SD_CARD_SS: ESP1.24 (GPIO15), ESP1.38 (GPIO22)
/ESP_CONTROL.BUSRQ: D9.1 (K), DIAG-ESP_CONTROL1.5, IC1.1 (1OE), J12.8, RN3.6 (R5), SPI-ESP_CONTROL.OUT1.4 (QE)
/ESP_CONTROL.IORQ: DIAG-ESP_CONTROL1.3, IC1.6 (1A2), IC1.13 (2A2), J12.4, RN3.4 (R3), SPI-ESP_CONTROL.OUT1.2 (QC)
/ESP_CONTROL.MEMRQ: DIAG-ESP_CONTROL1.4, IC1.8 (1A3), IC1.11 (2A3), J12.6, RN3.5 (R4), SPI-ESP_CONTROL.OUT1.3 (QD)
/ESP_CONTROL.NMI: D6.1 (K), DIAG-ESP_CONTROL1.8, RN3.9 (R8), SPI-ESP_CONTROL.OUT1.7 (QH)
/ESP_CONTROL.RD: DIAG-ESP_CONTROL1.1, IC1.2 (1A0), IC1.17 (2A0), RN3.2 (R1), SPI-ESP_CONTROL.OUT1.15 (QA)
/ESP_CONTROL.ROMCS: D7.1 (K), DIAG-ESP_CONTROL1.7, J12.10, RN3.8 (R7), SPI-ESP_CONTROL.OUT1.6 (QG)
/ESP_CONTROL.WAIT: D8.1 (K), DIAG-ESP_CONTROL1.6, RN3.7 (R6), SPI-ESP_CONTROL.OUT1.5 (QF)
/ESP_CONTROL.WR: DIAG-ESP_CONTROL1.2, IC2.2, J12.2, RN3.3 (R2), SPI-ESP_CONTROL.OUT1.1 (QB), SPI-LOCAL_DATA.OUT1.13 (~OE)
/ESP_HARDLOCK: ESP1.26 (GPIO2), J12.18
/ESP_ROMSEL_0: ESP1.23 (GPIO7), J12.14
/ESP_ROMSEL_1: ESP1.22 (GPIO6), J12.16
/ESP_ROM_WR_PROTECT: ESP1.28 (GPIO4), J12.12
/ESP_WAIT_RESET: ESP1.18 (GPIO11), J3.11
/IOCACHE-128K_ZXspectrum/CACHE_CE2: CACHE1.30 (CE2#), R8.1
/IORQ_FILTER_BIT: J3.1, JP2.2
/LOCAL_A0: CACHE1.12 (A0), DIAG-LOCAL_ADD_LOW1.1, IC3.15 (Q0), SPI-LOCAL_ADDR_L.IN1.11 (D0), SPI-LOCAL_ADD_L.OUT1.15 (QA), Z80_ADDRLOW1.18 (B0)
/LOCAL_A1: CACHE1.11 (A1), DIAG-LOCAL_ADD_LOW1.2, IC3.1 (Q1), SPI-LOCAL_ADDR_L.IN1.12 (D1), SPI-LOCAL_ADD_L.OUT1.1 (QB), Z80_ADDRLOW1.17 (B1)
/LOCAL_A2: CACHE1.10 (A2), DIAG-LOCAL_ADD_LOW1.3, IC3.2 (Q2), SPI-LOCAL_ADDR_L.IN1.13 (D2), SPI-LOCAL_ADD_L.OUT1.2 (QC), Z80_ADDRLOW1.16 (B2)
/LOCAL_A3: CACHE1.9 (A3), DIAG-LOCAL_ADD_LOW1.4, IC3.3 (Q3), SPI-LOCAL_ADDR_L.IN1.14 (D3), SPI-LOCAL_ADD_L.OUT1.3 (QD), Z80_ADDRLOW1.15 (B3)
/LOCAL_A4: CACHE1.8 (A4), DIAG-LOCAL_ADD_LOW1.5, IC3.4 (Q4), SPI-LOCAL_ADDR_L.IN1.3 (D4), SPI-LOCAL_ADD_L.OUT1.4 (QE), Z80_ADDRLOW1.14 (B4)
/LOCAL_A5: CACHE1.7 (A5), DIAG-LOCAL_ADD_LOW1.6, IC3.5 (Q5), SPI-LOCAL_ADDR_L.IN1.4 (D5), SPI-LOCAL_ADD_L.OUT1.5 (QF), Z80_ADDRLOW1.13 (B5)
/LOCAL_A6: CACHE1.6 (A6), DIAG-LOCAL_ADD_LOW1.7, IC3.6 (Q6), SPI-LOCAL_ADDR_L.IN1.5 (D6), SPI-LOCAL_ADD_L.OUT1.6 (QG), Z80_ADDRLOW1.12 (B6)
/LOCAL_A7: CACHE1.5 (A7), DIAG-LOCAL_ADD_LOW1.8, IC3.7 (Q7), SPI-LOCAL_ADDR_L.IN1.6 (D7), SPI-LOCAL_ADD_L.OUT1.7 (QH), Z80_ADDRLOW1.11 (B7)
/LOCAL_A8: CACHE1.27 (A8), DIAG-LOCAL_ADD_HIGH1.1, IC4.15 (Q0), SPI-LOCAL_ADD_H.IN1.11 (D0), SPI-LOCAL_ADD_HIGH.OUT1.15 (QA), Z80_ADDRHIGH1.18 (B0)
/LOCAL_A9: CACHE1.26 (A9), DIAG-LOCAL_ADD_HIGH1.2, IC4.1 (Q1), SPI-LOCAL_ADD_H.IN1.12 (D1), SPI-LOCAL_ADD_HIGH.OUT1.1 (QB), Z80_ADDRHIGH1.17 (B1)
/LOCAL_A10: CACHE1.25 (A11), DIAG-LOCAL_ADD_HIGH1.3, IC4.2 (Q2), SPI-LOCAL_ADD_H.IN1.13 (D2), SPI-LOCAL_ADD_HIGH.OUT1.2 (QC), Z80_ADDRHIGH1.16 (B2)
/LOCAL_A11: CACHE1.23 (A10), DIAG-LOCAL_ADD_HIGH1.4, IC4.3 (Q3), SPI-LOCAL_ADD_H.IN1.14 (D3), SPI-LOCAL_ADD_HIGH.OUT1.3 (QD), Z80_ADDRHIGH1.15 (B3)
/LOCAL_A12: DIAG-LOCAL_ADD_HIGH1.5, SPI-LOCAL_ADD_H.IN1.3 (D4), SPI-LOCAL_ADD_HIGH.OUT1.4 (QE), Z80_ADDRHIGH1.14 (B4)
/LOCAL_A13: DIAG-LOCAL_ADD_HIGH1.6, SPI-LOCAL_ADD_H.IN1.4 (D5), SPI-LOCAL_ADD_HIGH.OUT1.5 (QF), Z80_ADDRHIGH1.13 (B5)
/LOCAL_A14: DIAG-LOCAL_ADD_HIGH1.7, SPI-LOCAL_ADD_H.IN1.5 (D6), SPI-LOCAL_ADD_HIGH.OUT1.6 (QG), Z80_ADDRHIGH1.12 (B6)
/LOCAL_A15: DIAG-LOCAL_ADD_HIGH1.8, SPI-LOCAL_ADD_H.IN1.6 (D7), SPI-LOCAL_ADD_HIGH.OUT1.7 (QH), Z80_ADDRHIGH1.11 (B7)
/LOCAL_CONTROL.IORQ: IC1.14 (1Y2), J12.17, RN1.3 (R2)
/LOCAL_CONTROL.MEMRQ: IC1.12 (1Y3), J12.19, RN1.2 (R1)
/LOCAL_CONTROL.RD: IC1.18 (1Y0), J12.13, RN1.5 (R4)
/LOCAL_CONTROL.WR: IC1.16 (1Y1), J12.15, RN1.4 (R3)
/LOCAL_D0: CACHE1.13 (DQ0), DIAG-LOCAL_DATA1.1, RN2.2 (R1), SPI-LOCAL_DATA.IN1.11 (D0), SPI-LOCAL_DATA.OUT1.15 (QA), Z80-LOCAL_DATA1.18 (B0)
/LOCAL_D1: CACHE1.14 (DQ1), DIAG-LOCAL_DATA1.2, RN2.3 (R2), SPI-LOCAL_DATA.IN1.12 (D1), SPI-LOCAL_DATA.OUT1.1 (QB), Z80-LOCAL_DATA1.17 (B1)
/LOCAL_D2: CACHE1.15 (DQ2), DIAG-LOCAL_DATA1.3, RN2.4 (R3), SPI-LOCAL_DATA.IN1.13 (D2), SPI-LOCAL_DATA.OUT1.2 (QC), Z80-LOCAL_DATA1.16 (B2)
/LOCAL_D3: CACHE1.17 (DQ3), DIAG-LOCAL_DATA1.4, RN2.5 (R4), SPI-LOCAL_DATA.IN1.14 (D3), SPI-LOCAL_DATA.OUT1.3 (QD), Z80-LOCAL_DATA1.15 (B3)
/LOCAL_D4: CACHE1.18 (DQ4), DIAG-LOCAL_DATA1.5, RN2.6 (R5), SPI-LOCAL_DATA.IN1.3 (D4), SPI-LOCAL_DATA.OUT1.4 (QE), Z80-LOCAL_DATA1.14 (B4)
/LOCAL_D5: CACHE1.19 (DQ5), DIAG-LOCAL_DATA1.6, RN2.7 (R6), SPI-LOCAL_DATA.IN1.4 (D5), SPI-LOCAL_DATA.OUT1.5 (QF), Z80-LOCAL_DATA1.13 (B5)
/LOCAL_D6: CACHE1.20 (DQ6), DIAG-LOCAL_DATA1.7, RN2.8 (R7), SPI-LOCAL_DATA.IN1.5 (D6), SPI-LOCAL_DATA.OUT1.6 (QG), Z80-LOCAL_DATA1.12 (B6)
/LOCAL_D7: CACHE1.21 (DQ7), DIAG-LOCAL_DATA1.8, RN2.9 (R8), SPI-LOCAL_DATA.IN1.6 (D7), SPI-LOCAL_DATA.OUT1.7 (QH), Z80-LOCAL_DATA1.11 (B7)
/PERM_Z80_IORQ: J3.24, RIO_DECODER1.19 (CE)
/RIO-128K_ZXspectrum/RIO_CE2: R5.2, RIO1.30 (CE2#)
/RIO-128K_ZXspectrum/ROM_D0: RIO1.13 (DQ0), RIO_DECODER1.2 (A0), Z80-RIO_DATA1.18 (B0)
/RIO-128K_ZXspectrum/ROM_D1: RIO1.14 (DQ1), RIO_DECODER1.3 (A1), Z80-RIO_DATA1.17 (B1)
/RIO-128K_ZXspectrum/ROM_D2: RIO1.15 (DQ2), RIO_DECODER1.4 (A2), Z80-RIO_DATA1.16 (B2)
/RIO-128K_ZXspectrum/ROM_D3: RIO1.17 (DQ3), RIO_DECODER1.5 (A3), Z80-RIO_DATA1.15 (B3)
/RIO-128K_ZXspectrum/ROM_D4: RIO1.18 (DQ4), RIO_DECODER1.6 (A4), Z80-RIO_DATA1.14 (B4)
/RIO-128K_ZXspectrum/ROM_D5: RIO1.19 (DQ5), RIO_DECODER1.7 (A5), Z80-RIO_DATA1.13 (B5)
/RIO-128K_ZXspectrum/ROM_D6: RIO1.20 (DQ6), RIO_DECODER1.8 (A6), Z80-RIO_DATA1.12 (B6)
/RIO-128K_ZXspectrum/ROM_D7: RIO1.21 (DQ7), RIO_DECODER1.9 (A7), Z80-RIO_DATA1.11 (B7)
/RIO_CONTROL.A14: J3.17, RIO1.3 (A14)
/RIO_CONTROL.A15: J3.19, RIO1.31 (A15)
/RIO_CONTROL.OE: J3.23, RIO1.24 (OE#), Z80-RIO_DATA1.1 (A->B)
/RIO_CONTROL.WE: J3.21, RIO1.29 (WE#)
/SPI-Z80-BUS_ZXspectrum/ESP_CONTROL.WR+ESP_PULSE: IC1.4 (1A1), IC1.15 (2A1), IC2.3
/WAIT_IO: J3.7, RIO_DECODER1.13 (B5)
/Z80_A0: J1.18, JP2.3, RIO1.12 (A0), Z80_ADDRLOW1.2 (A0)
/Z80_A1: J1.17, RIO1.11 (A1), Z80_ADDRLOW1.3 (A1)
/Z80_A2: J1.16, RIO1.10 (A2), Z80_ADDRLOW1.4 (A2)
/Z80_A3: J1.15, RIO1.9 (A3), Z80_ADDRLOW1.5 (A3)
/Z80_A4: J1.14, RIO1.8 (A4), Z80_ADDRLOW1.6 (A4)
/Z80_A5: J1.13, RIO1.7 (A5), Z80_ADDRLOW1.7 (A5)
/Z80_A6: J1.12, RIO1.6 (A6), Z80_ADDRLOW1.8 (A6)
/Z80_A7: J1.11, RIO1.5 (A7), Z80_ADDRLOW1.9 (A7)
/Z80_A8: J1.26, RIO1.27 (A8), Z80_ADDRHIGH1.2 (A0)
/Z80_A9: J1.25, RIO1.26 (A9), Z80_ADDRHIGH1.3 (A1)
/Z80_A10: J1.24, RIO1.23 (A10), Z80_ADDRHIGH1.4 (A2)
/Z80_A11: J1.23, RIO1.25 (A11), Z80_ADDRHIGH1.5 (A3)
/Z80_A12: J1.22, RIO1.4 (A12), Z80_ADDRHIGH1.6 (A4)
/Z80_A13: J1.21, RIO1.28 (A13), Z80_ADDRHIGH1.7 (A5)
/Z80_A14: J1.20, J3.15, Z80_ADDRHIGH1.8 (A6)
/Z80_A15: J1.19, J3.13, Z80_ADDRHIGH1.9 (A7)
/Z80_BUS_CONTROL.Z80_ADD_DIR: J3.4, Z80_ADDRHIGH1.1 (A->B), Z80_ADDRLOW1.1 (A->B)
/Z80_BUS_CONTROL.Z80_ADD_OE: J3.2, Z80_ADDRHIGH1.19 (CE), Z80_ADDRLOW1.19 (CE)
/Z80_BUS_CONTROL.Z80_DATA_DIR: J3.6, Z80-LOCAL_DATA1.1 (A->B)
/Z80_BUS_CONTROL.Z80_DATA_OE: J3.8, Z80-LOCAL_DATA1.19 (CE)
/Z80_CONTROL.BUSACK: D5.1 (K), DIAG-Z80_CONTROL1.8, J1.9, SPI-Z80_CONTROL.IN1.5 (D6)
/Z80_CONTROL.BUSRQ: D9.2 (A), DIAG-Z80_CONTROL1.5, J1.5, J12.9, SPI-Z80_CONTROL.IN1.3 (D4)
/Z80_CONTROL.IORQ: DIAG-Z80_CONTROL1.3, IC1.7 (2Y2), J1.3, J12.5, SPI-Z80_CONTROL.IN1.13 (D2)
/Z80_CONTROL.MEMRQ: DIAG-Z80_CONTROL1.4, IC1.9 (2Y3), J1.4, J12.7, SPI-Z80_CONTROL.IN1.14 (D3)
/Z80_CONTROL.NMI: D6.2 (A), DIAG-Z80_CONTROL1.7, J1.7, SPI-Z80_CONTROL.IN1.6 (D7)
/Z80_CONTROL.RD: DIAG-Z80_CONTROL1.1, IC1.3 (2Y0), J1.1, J12.1, SPI-Z80_CONTROL.IN1.11 (D0)
/Z80_CONTROL.RESET: D2.2 (A), J1.10, JP1.1
/Z80_CONTROL.ROMCS: D7.2 (A), J1.8
/Z80_CONTROL.WAIT: D3.1 (K), D8.2 (A), DIAG-Z80_CONTROL1.6, J1.6, J12.11, SPI-Z80_CONTROL.IN1.4 (D5)
/Z80_CONTROL.WR: DIAG-Z80_CONTROL1.2, IC1.5 (2Y1), J1.2, J12.3, SPI-Z80_CONTROL.IN1.12 (D1)
/Z80_D0: J1.34, Z80-LOCAL_DATA1.2 (A0), Z80-RIO_DATA1.2 (A0)
/Z80_D1: J1.33, Z80-LOCAL_DATA1.3 (A1), Z80-RIO_DATA1.3 (A1)
/Z80_D2: J1.32, Z80-LOCAL_DATA1.4 (A2), Z80-RIO_DATA1.4 (A2)
/Z80_D3: J1.31, Z80-LOCAL_DATA1.5 (A3), Z80-RIO_DATA1.5 (A3)
/Z80_D4: J1.30, Z80-LOCAL_DATA1.6 (A4), Z80-RIO_DATA1.6 (A4)
/Z80_D5: J1.29, Z80-LOCAL_DATA1.7 (A5), Z80-RIO_DATA1.7 (A5)
/Z80_D6: J1.28, Z80-LOCAL_DATA1.8 (A6), Z80-RIO_DATA1.8 (A6)
/Z80_D7: J1.27, Z80-LOCAL_DATA1.9 (A7), Z80-RIO_DATA1.9 (A7)
/Z80_HARDLOCK: ESP1.4 (GPIO39), IC3.10 (~MRC), IC4.10 (~MRC), J3.20
/Z80_HARDLOCK_RESET: D4.1 (K), J3.3, RIO_DECODER1.12 (B6)
/Z80_HARDLOCK_SET: J3.5, RIO_DECODER1.11 (B7)
GND: C1.2, C2.2, C3.2, CACHE1.16 (VSS), D1.1 (K), ESP1.21 (GND), ESP1.34 (GND), ESP1.40 (GND), EX_SPI1.6, IC1.10 (GND), IC2.4, IC2.5, IC2.7 (GND), IC2.9, IC2.10, IC2.12, IC2.13, IC3.8 (GND), IC4.8 (GND), J1.40, J12.23, JP1.2, JP2.1, R3.1, RIO1.16 (VSS), RIO_DECODER1.10 (GND), SPI-ESP_CONTROL.OUT1.8 (GND), SPI-LOCAL_ADDR_L.IN1.8 (GND), SPI-LOCAL_ADD_H.IN1.8 (GND), SPI-LOCAL_ADD_HIGH.OUT1.8 (GND), SPI-LOCAL_ADD_L.OUT1.8 (GND), SPI-LOCAL_DATA.IN1.8 (GND), SPI-LOCAL_DATA.IN1.10 (DS), SPI-LOCAL_DATA.OUT1.8 (GND), SPI-Z80_CONTROL.IN1.8 (GND), Z80-LOCAL_DATA1.10 (GND), Z80-RIO_DATA1.10 (GND), Z80_ADDRHIGH1.10 (GND), Z80_ADDRLOW1.10 (GND)
unnamed: D1.2 (A), R1.2
unnamed: D2.1 (K), ESP1.35 (GPIO21)
unnamed: D10.1 (K), RN1.1 (common)
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

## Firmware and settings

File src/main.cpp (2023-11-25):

#include <Arduino.h>
#include <SPI.h>

#include <ESPTests.h>
#include <Z80Tests.h>

/*
  PORT A -- Z80 DATA

  PORT B -- 0123 SPI

  PORT F -- Z80 ADDRESS LOW
  PORT K -- Z80 ADDRESS HIGH
*/

uint8_t *localPacket;

void printLocalPacket()
{
  Serial.print("localPacket : 0[");
  Serial.print(localPacket[0], HEX);
  Serial.print("] 1[");
  Serial.print(localPacket[1], HEX);
  Serial.print("] 2[");
  Serial.print(localPacket[2], HEX);
  Serial.print("] 3[");
  Serial.print(localPacket[3], HEX);
  Serial.println("]");
}




void setup()
{
  // put your setup code here, to run once:

  //Serial.begin(115000);
  Serial.begin(9600);
  Serial.println("Running.");

  pinMode(LED_BUILTIN, OUTPUT);

  // Set pin start-up states

  // ESP SPI
  
  ESP_setup();
  

  // Z80
  Z80_setup();


}

void loop()
{
  Serial.println("\n\nTEST LOOP START");
  // put your main code here, to run repeatedly:

  
    // Blinky code for enable to test if running
    /*
    digitalWrite(LED_BUILTIN, HIGH);
    delay(250);
    digitalWrite(LED_BUILTIN, LOW);
    delay(1000);
    */

  //
  // BASIC LOCAL ESP FUNCTION TESTING
  //

  //
  //  ESP Cache Tests
  //  
  ESP_CACHE_Status_Access_Test(); // WORKING (SIM)
  ESP_CACHE_Data_Access_Test();  // SIM FAILS on Addr 0?
  
  //
  //  ESP RIO function tests
  //
  ESP_RIO_ROM_Access_Test();
  ESP_RIO_IODconfig_Access_Test();  // SIM PASSES BUT RIO CONFIG EMPTY?  -- CANT READ ON VERSION 2 BOARD!
    


  // BASIC Z80 FUNCTION TESTING  

  //
  // RIO ROM Tests
  //
    
  enableRIO_ROMRW(0);
  Z80_ROMMemory_Test();
  disableRIO_ROM();
  /*
  enableRIO_ROMRW(1);
  Z80_ROMMemory_Test();
  enableRIO_ROMRW(2);
  Z80_ROMMemory_Test();
  enableRIO_ROMRW(3);
  Z80_ROMMemory_Test();
  disableRIO_ROM();
  */

    
//
// IODdevice TEST
//  


ESP_RIOconfig_Cache0to0x0001();
Z80_IORQ_Test();
  
Serial.println("\n\nTEST LOOP END");
}

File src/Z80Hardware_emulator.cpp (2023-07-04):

#include <Z80Hardware_emulator.h>

# define RUNSLOW true
# define SLOWTIME 200
# define SLOWPULSEDIV 1

#define PORT_DDR_OUTPUT 255
#define PORT_DDR_INPUT 0


// Z80 BUS Assignments
#define Z80_DATA_out PORTA
#define Z80_DATA_in  PINA
#define Z80_DATA_DDR DDRA

#define Z80_ADDR_L      PORTF
#define Z80_ADDR_L_DDR  DDRF

#define Z80_ADDR_H      PORTK
#define Z80_ADDR_H_DDR  DDRK

// Z80 Control Assignments
#define Z80_BUSACK 30   // OUTPUT -- Response to external devices BUSRQ
#define Z80_RD     21   // OUTPUT -- Read operation
#define Z80_WR     20   // OUTPUT -- Write operation (pulse)
#define Z80_IORQ   19   // OUTPUT -- IO Access operation
#define Z80_MEMRQ  18   // OUTPUT -- Memory Access operation
#define Z80_BUSRQ  17    // INPUT -- External device requesting control of the BUS
#define Z80_WAIT   16   // INPUT  -- Z80 enter WAIT mode
#define Z80_ROMCS  15   // INPUT  -- ZX spectrum ROM access (ROM access decoded Via ULA MEMRQ+A14+A15)
#define Z80_NMI    14   // INPUT  -- Z80 NMI trigger


#define Z80_SIM_ISR 2   // [INTERRUPT] 
// OTHER Z80 CPU PINS
//  M1      // OUTPUT -- Extend T-State
//  RFSH    // OUTPUT -- DRAM refresh?
//  HALT    // OUTPUT -- LOW when Z80 executes HALT instructions, Z80 waiting (in a NOP loop) for NMI or INT to occur
//  INT     // INPUT  -- Interupt request
//  RESET   // INPUT  -- Reset the Z80
//  CLK     // INPUT  -- Clock signal driving Z80


//
// Z80 OUTPUT Control line operations 
//

// SEND conditions should set pull-ups?

void sendZ80_WR(void)
{
    pinMode(Z80_WR, OUTPUT);
    digitalWrite(Z80_WR, LOW);
    if (RUNSLOW)
    {
        delay(SLOWTIME / SLOWPULSEDIV);
    };
    digitalWrite(Z80_WR, HIGH);
}
void clearZ80_WRactive(void)        {   pinMode(Z80_WR, OUTPUT);        digitalWrite(Z80_WR, HIGH);     }
void clearZ80_WRpassive(void)       {   pinMode(Z80_WR, INPUT);         digitalWrite(Z80_WR, LOW);      }

void sendZ80_RD(void)               {   pinMode(Z80_RD, OUTPUT);        digitalWrite(Z80_RD, LOW);      }
void clearZ80_RDactive(void)        {   pinMode(Z80_RD, OUTPUT);        digitalWrite(Z80_RD, HIGH);     }
void clearZ80_RDpassive(void)       {   pinMode(Z80_RD, INPUT);         digitalWrite(Z80_RD, LOW);      }

void sendZ80_IORQ(void)             {   pinMode(Z80_IORQ, OUTPUT);      digitalWrite(Z80_IORQ, LOW);    }
void clearZ80_IORQactive(void)      {   pinMode(Z80_IORQ, OUTPUT);      digitalWrite(Z80_IORQ, HIGH);   }
void clearZ80_IORQpassive(void)     {   pinMode(Z80_IORQ, INPUT);       digitalWrite(Z80_IORQ, LOW);    }

void sendZ80_MEMRQ(void)            {   pinMode(Z80_MEMRQ, OUTPUT);     digitalWrite(Z80_MEMRQ, LOW);   }
void clearZ80_MEMRQactive(void)     {   pinMode(Z80_MEMRQ, OUTPUT);     digitalWrite(Z80_MEMRQ, HIGH);  }
void clearZ80_MEMRQpassive(void)    {   pinMode(Z80_MEMRQ, INPUT);      digitalWrite(Z80_MEMRQ, LOW);   }

void sendZ80_BUSACK(void)           {   pinMode(Z80_BUSACK, OUTPUT);    digitalWrite(Z80_BUSACK, LOW);  }
void clearZ80_BUSACK(void)          {   pinMode(Z80_BUSACK, OUTPUT);    digitalWrite(Z80_BUSACK, HIGH); }


//
// Z80 INPUT Control line operations (Return TRUE if LOW)
boolean isWAIT(void)     
{
    if(digitalRead(Z80_WAIT) == 0) { return true; }
    else { return false; }
}
//boolean checkINT(void)      {   return !digitalRead(Z80_INT)    ;}
boolean isNMI(void)      
{   
    if(digitalRead(Z80_NMI) == 0) { return true; }
    else { return false; }
}
//boolean checkRESET(void)    {   return !digitalRead(Z80_RESET); }
boolean isBUSRQ(void)    
{   
     if(digitalRead(Z80_BUSRQ) == 0) 
     { Serial.println("Z80_BUSRQ = 0");
        return true; }
     else { 
        Serial.println("Z80_BUSRQ = 1");
        return false; }
}
  

void enableZ80_ADDRpullups (void) 
{   
    // Pins pulled high with internal 10K (bus pulled up for input)
    Z80_ADDR_L_DDR = PORT_DDR_INPUT;
    Z80_ADDR_H_DDR = PORT_DDR_INPUT;
    Z80_ADDR_L = 255;
    Z80_ADDR_H = 255;
    return;
}

void disableZ80_ADDRpullups (void) 
{
    // Tri-state the pins (disconnect from bus)
    Z80_ADDR_L_DDR = PORT_DDR_INPUT;
    Z80_ADDR_H_DDR = PORT_DDR_INPUT;
    Z80_ADDR_L = 0;
    Z80_ADDR_H = 0;
    return;
}

void enableZ80_DATApullups (void)
{
    // Pins pulled high with internal 10K (bus pulled up for input)
    Z80_DATA_DDR = PORT_DDR_INPUT;
    Z80_DATA_out = 255;
}

void disableZ80_DATApullups (void)
{
    // Tri-state the pins (disconnect from bus)
    Z80_DATA_DDR = PORT_DDR_INPUT;
    Z80_DATA_out = 0;
}

void clearZ80_ADDRpassive(void)
{
    // Function leaves the ports in INPUT mode (Tri-state)
    disableZ80_ADDRpullups();    
    return;
}

void clearZ80_DATApassive(void)
{ 
    // Function leaves the ports in INPUT mode (Tri-state)
    disableZ80_DATApullups();
    return;
}
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

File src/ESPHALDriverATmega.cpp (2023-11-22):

#include <ESPHALDriverATmega.h>
#include "consoleDebug.h"

#define DEBUG_SPI_READ false
#define DEBUG_SPI_WRITE false
#define DEBUG_SPI_FORMAT HEX // BIN / HEX /DEC



#define RUNSLOW false
#define SLOWTIME 100
#define SLOWPULSEDIV 5



//void transfer(void *buf, size_t count)

//
// PIN Map


// ARDUINO SPI PINS
// SPI SS   53
// SPI SCK  52
// SPI MOSI 51
// SPI MISO 50

#define SS_START LOW
#define SS_STOP HIGH


#define ESP_SPI_INT_STC 49  // OUTPUT (pulse)     --SPI Latch Bus packet in shift registers for output
#define ESP_SPI_INT_OE 48   // OUTPUT (send/stop) --SPI Enable Output of an Address from shift registers
#define ESP_PULSE 47        // OUTPUT (pulse)     -- Generate a pulse for Writing
#define ESP_SPI_INT_PL 46   // OUTPUT (pulse)     -- SPI Load Host BUS state to shift registers
#define ESP_SPI_INT_CE 41   // OUTPUT


#define ESP_RIO_PROTECT 5   // OUTPUT (enable/disable)
#define ESP_RESET 6         // OUTPUT LOW RESETS HOST
#define ESP_INT 3           // INPUT  [INTERRUPT]

#define ESP_WAIT_RESET 8    // OUTPUT (pulse)
#define Z80_HARDLOCK 9      // INPUT  (get)
#define ESP_HARDLOCK 10     // OUTPUT (set/release)
#define ESP_ROMSELECT0 11   // OUTPUT (select ROM)
#define ESP_ROMSELECT1 12   // OUTPUT (select ROM)


//
// BUS BusPacketBuffer

/* 
  BUS PACKET BYTES
    BusPacketBuffer[3] = Data;
    BusPacketBuffer[2] = Control;
    BusPacketBuffer[1] = loAddr;
    BusPacketBuffer[0] = hiAddr;
*/

uint8_t BusPacketBuffer[4]; 

void clearBusPacketBuffer (void)
{
  BusPacketBuffer[3] = 0xFF; // Data
  BusPacketBuffer[2] = 0xFF; // Control
  BusPacketBuffer[1] = 0xFF; // LoAddr
  BusPacketBuffer[0] = 0xFF; // HiAddr
}

uint8_t * setBusPacketBuffer (uint8_t Data, uint8_t Control, uint16_t Address)
{

  uint8_t loAddr = (uint8_t)(Address);
  uint8_t hiAddr = (uint8_t)(Address >> 8);

  BusPacketBuffer[3] = Data;
  BusPacketBuffer[2] = Control;
  BusPacketBuffer[1] = loAddr;
  BusPacketBuffer[0] = hiAddr;

  return BusPacketBuffer;
}

//
// SPI BUS hardware implementation


SPISettings myTXSpiSettings (100000,MSBFIRST,SPI_MODE0);
SPISettings myRXSpiSettings (100000,MSBFIRST,SPI_MODE0);  // IF clock is inverted to 165s
//SPISettings myRXSpiSettings (1000000,MSBFIRST,SPI_MODE2); // IF clock is NOT inverted to 165s
#define LATCHINGDELAY 30

// WRITE method for the bus hardware
void writeSPI(void)
{ 
  // OUTPUT 74XX595 Shift registers (x4)

  if(DEBUG_SPI_WRITE) { consoleShowBusPacketBuffer("writeSPI",BusPacketBuffer,DEBUG_SPI_FORMAT); }

  // Load TXPacket into the Shift Regs
  SPI.beginTransaction(myTXSpiSettings);
  SPI.transfer(BusPacketBuffer,4);  
  SPI.endTransaction();

  // LATCH the Shift Regs to Storage (pulse)
  digitalWrite(ESP_SPI_INT_STC, HIGH); // Move shift to storage  
  delayMicroseconds(LATCHINGDELAY);
  if(RUNSLOW) { delay(SLOWTIME); } // SLOW THE OUTPUT POINT
  digitalWrite(ESP_SPI_INT_STC, LOW);
    
  return;
}

// READ method for the bus hardware
void readSPI(void)
{ 
  // INPUT 74xx165 Shift Registers (x4)

  // LATCH data into the Shift Regs (pulse)
  digitalWrite(ESP_SPI_INT_PL, LOW);  // Parallel Load
  if(RUNSLOW) { delay(SLOWTIME); }  // SLOW THE INPUT POINT
  delayMicroseconds(LATCHINGDELAY);
  digitalWrite(ESP_SPI_INT_PL, HIGH); // Serial Shift
  
  //clearBusPacketBuffer();
  SPI.beginTransaction(myRXSpiSettings);
  SPI.transfer(BusPacketBuffer,4);  
  SPI.endTransaction(); 
  
  // Needed if Shift registers are chained using !Q7
  //BusPacketBuffer[0] = ~BusPacketBuffer[0];
  //BusPacketBuffer[2] = ~BusPacketBuffer[2];

  if(DEBUG_SPI_READ) { consoleShowBusPacketBuffer("readSPI",BusPacketBuffer,DEBUG_SPI_FORMAT); }
  
  return; // results in BusPacketBuffer
}

// SPI BUS signal output controls
// The output from the 595s on the SPI bus must ONLY be activated when RIO's 245 Decoder is disabled.
// This code is likely to be replaced with a NOT gate that inverts the OE signal from RIO's 245 Decoder chip, so we can never conflict the LOCAL HIGH ADDR BYTE

void sendBusSignalsFromSPI(void)
{
  digitalWrite(ESP_SPI_INT_OE, LOW);
}

void stopBusSignalsFromSPI(void)
{
  digitalWrite(ESP_SPI_INT_OE, HIGH);
}



//
// Interface for Hardware Abstraction Layer


void Setup_ESPHALDriver(void)
{
  SPI.begin();

  // INPUT PINS
  pinMode(Z80_HARDLOCK, INPUT);
  digitalWrite(Z80_HARDLOCK, LOW); // Tri-State

  // ESP pin Config
  pinMode(ESP_SPI_INT_CE, OUTPUT);
  pinMode(ESP_SPI_INT_STC, OUTPUT);
  pinMode(ESP_SPI_INT_OE, OUTPUT);
  pinMode(ESP_PULSE, OUTPUT);
  pinMode(ESP_SPI_INT_PL, OUTPUT);
  pinMode(ESP_RIO_PROTECT, OUTPUT);
  pinMode(ESP_ROMSELECT0, OUTPUT);
  pinMode(ESP_ROMSELECT1, OUTPUT);
  pinMode(ESP_HARDLOCK, OUTPUT);
  pinMode(ESP_RIO_PROTECT, OUTPUT);
  pinMode(ESP_RESET, OUTPUT);

  // OUTPUT States
  digitalWrite(ESP_SPI_INT_CE, LOW);
  digitalWrite(ESP_SPI_INT_STC, HIGH);
  digitalWrite(ESP_SPI_INT_OE, HIGH);
  digitalWrite(ESP_PULSE, HIGH);
  digitalWrite(ESP_SPI_INT_PL, HIGH);
  digitalWrite(ESP_RIO_PROTECT, HIGH);  // WRITE ENABLE LOW
  digitalWrite(ESP_ROMSELECT0, LOW);
  digitalWrite(ESP_ROMSELECT1, LOW);
  digitalWrite(ESP_HARDLOCK, HIGH);     // START LOCKED
  digitalWrite(ESP_RIO_PROTECT, HIGH);  // Connect on LOW (may be buffer with NOT?)
  digitalWrite(ESP_RESET, LOW);
  return;
}


void WriteDataBUSOperation(uint8_t Data, uint8_t Control, uint16_t Address)
{
  digitalWrite(SS,SS_START);
  setBusPacketBuffer(Data,Control,Address);  
  writeSPI(); // Set Control and Address lines
  // sendBusSignalsFromSPI();  // ADDRESS BUS CONNECTED AFTER ESP HARDLOCK
  sendPulse();
  digitalWrite(SS,SS_STOP);
  return;
}

uint8_t ReadDataBUSOperation(uint8_t Control, uint16_t Address)
{ 
  digitalWrite(SS,SS_START);
  setBusPacketBuffer(0x00,Control,Address);  
  writeSPI(); // Set Control and Address lines
  // sendBusSignalsFromSPI();  // ADDRESS BUS CONNECTED AFTER ESP HARDLOCK
  readSPI();
  digitalWrite(SS,SS_STOP);
  return BusPacketBuffer[3]; // Data byte
}

uint8_t * getBUSstate(void) {
  readSPI();
  return BusPacketBuffer;
}


//
// RIO Hardware ROM/CACHE

void enableRIOProtection(void)
{
  digitalWrite(ESP_RIO_PROTECT, HIGH);
  return;
}

void disableRIOProtection(void)
{
  digitalWrite(ESP_RIO_PROTECT, LOW);
  return;
}

void setROMbank(uint8_t rom)
{
  switch (rom)
  {
  case 0:
    digitalWrite(ESP_ROMSELECT0,0);
    digitalWrite(ESP_ROMSELECT1,0);
    break;
  case 1:
    digitalWrite(ESP_ROMSELECT0,1);
    digitalWrite(ESP_ROMSELECT1,0);
    break;
  case 2:
    digitalWrite(ESP_ROMSELECT0,0);
    digitalWrite(ESP_ROMSELECT1,1);
    break;
  case 3:
    digitalWrite(ESP_ROMSELECT0,1);
    digitalWrite(ESP_ROMSELECT1,1);
    break;
  default:
    digitalWrite(ESP_ROMSELECT0,0);
    digitalWrite(ESP_ROMSELECT1,0);
    break;
  }

  return;
}


//
// OUTPUT send (Low/High)

void sendPulse(void)
{
  // Some actions need a low clock pulse to trigger
  // This pin should idel high
  digitalWrite(ESP_PULSE,LOW);
  if(RUNSLOW) { delay(SLOWTIME/SLOWPULSEDIV); }
  digitalWrite(ESP_PULSE,HIGH);
  return;
}
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

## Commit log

2022-10-30 z80 connect added, SPI bus fixed
    [main.cpp]
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2022-11-08 ESP BUS connection reworked
    [ESPemulation.cpp, main.cpp]
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2023-01-02 Fixed bug in ESPHardlock check
    [ESPemulation.cpp]
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2023-01-03 Removed CONTROL swapped pins to ROMselect
    [ESPSystemInterface.cpp, ESPemulation.cpp, main.cpp]
2023-01-03 Missed some calls on Controls (builds ok)
    [ESPSystemInterface.cpp, ESPemulation.cpp]
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2023-01-03 Fixed a bug in the Z80 memory ROM test
    [Z80Hardware_emulation.cpp, Z80Tests.cpp, main.cpp]
2023-01-03 Programmed IOd testing (failing)
    [ESPTests.cpp, Z80Hardware_emulation.cpp, Z80Tests.cpp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]
2023-01-03 Flipped the ESP Lock signal
    [Z80Hardware_emulation.cpp, main.cpp]
2023-01-03 Serial output for IOd testing (failing)
    [Z80Tests.cpp]
2023-01-04 massive bug hunt in the IOd space
    [Z80Hardware_emulation.cpp, main.cpp]
2023-01-07 Cache CS swaped notZ80HardLock to Z80PermittedIO
    [Z80Tests.cpp]
2023-01-07 ESP RESET HOST pin allocated
2023-01-07 ROMCS and ROM selection initial (Failing)
    [main.cpp]
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2023-01-19 Circuit fix, cross connection on 245 Data/Addr OE
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2023-05-09 KiCad PCB layout for freerouting test
    [CACHE.kicad_sch, CORE.kicad_sch, FujiNet_Z80Bus_Reference.kicad_sch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]
2023-05-09 Single PCB layout experiements
    [CORE.kicad_sch, FujiNet_Z80Bus_Reference.dsn, FujiNet_Z80Bus_Reference.kicad_pcb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]
2023-05-13 Massive fix to KiCad Labels
    [CACHE.kicad_sch, CORE.kicad_sch, FujiNet_Z80Bus_Reference.kicad_sch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]
2023-05-13 KiCad Labels mostly fixed
    [CACHE.kicad_sch, CORE.kicad_sch, FujiNet_Z80Bus_Reference.kicad_sch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]
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2023-05-14 KiCAD attempt to route a single board (failed)
    [CACHE.kicad_sch, CORE.kicad_sch, FujiNet_Z80Bus_Reference.dsn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]
2023-05-14 KiCad massive refactoring to enable modular PCB design
    [CACHE CONTROL.kicad_sch, CACHE.kicad_sch, CORE.kicad_sch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]
2023-05-16 Unpicked CoreLogic Buses, some symbol updates
    [CACHE CONTROL.kicad_sch, CACHE.kicad_sch, CORE.kicad_sch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]
2023-05-17 KiCAD Fully expanded Logic core connector
    [CACHE CONTROL.kicad_sch, CACHE.kicad_sch, CORE.kicad_sch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]
2023-05-17 KiCad forgot to fix the path on connector schem
    [CACHE CONTROL.kicad_sch, CACHE.kicad_sch, CORE.kicad_sch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]
2023-05-17 KiCad symbol library changes on logic core
    [CACHE CONTROL.kicad_sch, Logic core.kicad_sch, RIO CONTROL.kicad_sch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]
2023-05-17 KiCad experiment with logic core PCB
    [CACHE CONTROL.kicad_sch, Logic core connectors.kicad_sch, Logic core.dsn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]
2023-05-17 KiCad diode OR gate example added to Core
    [CORE.kicad_sch, Logic core.kicad_sch, SPIBUS.kicad_sch]
2023-05-17 Archiving old KiCAD 5 version
    [CACHE.kicad_sch, CACHE.sch, CORE.kicad_sch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]
2023-05-17 KiCAD fixed ESP Wrover Library references
2023-05-17 KiCad repairing grid alignment
    [CACHE CONTROL.kicad_sch, CACHE.kicad_sch, CORE.kicad_sch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]
2023-05-17 KiCAD - grid alignment errors fixed
    [CORE.kicad_sch, FujiNet_Z80Bus_ReferenceDesign.kicad_sch, Logic core connectors.kicad_sch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]
2023-05-17 Kicad Symbols error fixes and ERC bug fixes
    [CACHE CONTROL.kicad_sch, CORE.kicad_sch, FujiNet_Z80Bus_ReferenceDesign.kicad_sch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]
2023-05-18 KiCad - ALMOST ERROR FREE!!!!
    [CACHE.kicad_sch, CORE.kicad_sch, FujiNet_Z80Bus_ReferenceDesign.kicad_sch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]
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2023-05-18 KiCad - Library fixes and AS6C1008 memory added
    [CACHE.kicad_sch, CORE.kicad_sch, Logic core.kicad_sch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]
2023-05-19 KiCad - Swapped out RIO and CACHE symbols
    [CACHE.kicad_sch, CORE.kicad_sch, RIO.kicad_sch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]
2023-05-19 KiCad - last 5 errors
    [Logic core.kicad_sch]
2023-05-19 KiCAD PCB layout testing
    [CACHE.kicad_sch, CORE.kicad_sch, FujiNet_Z80Bus_ReferenceDesign.kicad_pcb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]
2023-05-20 KiCad close but failed attempt at PCB
    [CORE.kicad_sch, FujiNet_Z80Bus_ReferenceDesign.kicad_pcb, SPIBUS.kicad_sch]
2023-05-20 KiCAD - PSU LED fix
    [FujiNet_Z80Bus_ReferenceDesign.kicad_sch, SPIBUS.kicad_sch]
2023-05-20 KiCad - Fixed Hardlock SET/RESET issue on ERC
    [CACHE CONTROL.kicad_sch, CACHE.kicad_sch, CORE.kicad_sch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]
2023-05-20 KiCad - Refactoring RIO IOCACHE to projects
    [CORE.kicad_sch, FujiNet_Z80Bus_ReferenceDesign.kicad_pcb, FujiNet_Z80Bus_ReferenceDesign.kicad_sch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]
2023-05-20 KiCad - Refactor Z80_BUS to Z80-BUS_ZXspectrum48K
    [FujiNet_Z80Bus_ReferenceDesign.kicad_sch, Z80-BUS_ZXspectrum48K.kicad_pcb, Z80-BUS_ZXspectrum48K.kicad_sch]
2023-05-20 KiCad - Refactored Logic core to GLUE
    [CACHE CONTROL.kicad_sch, CORE.kicad_sch, CORE_ESP32-WROVER.kicad_pcb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]
2023-05-20 KiCad - Refactored the SPI bus
    [CACHE CONTROL.kicad_sch, CORE_ESP32-WROVER.kicad_sch, FujiNet_Z80Bus_ReferenceDesign.kicad_sch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]
2023-05-20 KiCad - Proof of concept PCB in-progress
    [CACHE CONTROL.kicad_sch, CORE_ESP32-WROVER.kicad_sch, FujiNet_Z80Bus_Reference.dsn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]
2023-05-21 KiCad Prototype routing (failed)
    [+.dsn, FujiNet_Z80Bus_ReferenceDesign.kicad_pcb, GLUE_ZXspectrum_connectors.kicad_sch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]
2023-05-21 KiCad - First prototype routed
    [FujiNet_Z80Bus_Reference.dsn, FujiNet_Z80Bus_ReferenceDesign.kicad_pcb, Z80-BUS_ZXspectrum48K.kicad_sch]
2023-05-21 KiCad - files for fabricating
    [FujiNet_Z80Bus_ReferenceDesign-B_Cu.gbr, FujiNet_Z80Bus_ReferenceDesign-B_Mask.gbr, FujiNet_Z80Bus_ReferenceDesign-B_Paste.gbr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]
2023-05-28 Reorganised the project again
    [CACHE CONTROL.kicad_sch, CORE_ESP32-WROVER.kicad_pcb, CORE_ESP32-WROVER.kicad_sch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]
2023-05-31 Fixed a bug A11 A10 mixed up on CACHE IC
    [FujiNet_Z80Bus_Reference.dsn, IOCACHE-128K_ZXspectrum.kicad_sch]
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2023-05-31 Fixed all the pathing issues in the projects. Added documentation and _impl project in each module to create PCBs
    [+.dsn, Bus track size calculator.ods, CORE_ESP32-WROVER.kicad_sch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]
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2023-06-01 GLUE is broken again, logic gate annotation issue
    [CACHE CONTROL.kicad_sch, GLUE_ZXspectrum.kicad_sch, GLUE_ZXspectrum_connectors.kicad_sch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]
2023-06-01 KiCad FIXED GLUE
    [CACHE CONTROL.kicad_sch, GLUE_ZXspectrum.kicad_sch, GLUE_ZXspectrum_connectors.kicad_sch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]
2023-06-01 KiCad GLUE PCB routed
    [GLUE_ZXspectrum_impl.dsn, GLUE_ZXspectrum_impl.kicad_pcb]
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2023-06-01 KiCad Origins for gerbers
    [CORE_ESP32-WROVER_impl.kicad_pcb, GLUE_ZXspectrum_impl.kicad_pcb, IOCACHE-128k_ZXspectrum_impl.kicad_pcb]
2023-06-01 Narrow versions of RIO CACHE
    [FujiNet_Modules_Template_impl.kicad_pcb, FujiNet_Modules_Template_impl.kicad_sch, GLUE_ZXspectrum.kicad_sch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]
2023-06-02 KiCad Attempted Concept design
    [..dsn, CORE_ESP32-WROVER.kicad_sch, GLUE_ZXspectrum_connectors.kicad_sch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]
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2023-06-02 KiCad Another attempt to route concept adapter
    [ZXspectrum_Concept.dsn, ZXspectrum_Concept.kicad_pcb]
2023-06-02 Kicad concept adapter still wont route
    [ZXspectrum_Concept.dsn, ZXspectrum_Concept.kicad_pcb]
2023-06-03 KiCad Cleaned up SPI schem
    [CACHE CONTROL.kicad_sch, CORE_ESP32-WROVER.kicad_sch, FujiNet_Z80Bus_ReferenceDesign.kicad_sch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]
2023-06-03 KiCad - SPI bus impl
    [SPI-Z80-BUS_ZXspectrum.kicad_sch, SPI-Z80-BUS_ZXspectrum_impl.dsn, SPI-Z80-BUS_ZXspectrum_impl.kicad_pcb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]
2023-06-03 KiCad Revision 2 of zxspectrum concept adapter
    [SPI-Z80-BUS_ZXspectrum_impl.kicad_pcb, ZXspectrum_Concept.kicad_pcb]
2023-06-03 KICad fixed SPI impl
    [SPI-Z80-BUS_ZXspectrum.kicad_sch, SPI-Z80-BUS_ZXspectrum_impl.dsn, SPI-Z80-BUS_ZXspectrum_impl.kicad_pcb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]
2023-06-03 KiCad Adapter Concept v2 pcb draft layout
    [..dsn, CACHE CONTROL.kicad_sch, CORE_ESP32-WROVER.kicad_sch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]
2023-06-03 KiCad adapter concept v2 for routing
    [ZXspectrum_Concept_v2.dsn, ZXspectrum_Concept_v2.kicad_pro.kicad_pcb]
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2023-06-04 KiCad Routing applied to concept adapter PCB
    [ZXspectrum_Concept_v2-routed.dsn, ZXspectrum_Concept_v2.kicad_pro.kicad_pcb]
2023-06-04 KiCad Removed PCB files from the modules
    [GLUE_ZXspectrum.kicad_pcb, RIO-128K_ZXspectrum.kicad_pcb, SPI-Z80-BUS_ZXspectrum.kicad_pcb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]
2023-06-04 KiCad - Gerber and drill exports, pre-fab prep
    [FujiNet_Modules_Template.kicad_pcb, IOCACHE-128K_ZXspectrum.kicad_sch, IOCACHE-128K_ZXspectrum_connectors.kicad_sch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]
2023-06-04 Fabrication setup for pcb2gcode
    [IOCACHE-128K_ZXspectrum.kicad_sch, IOCACHE-128K_ZXspectrum_connectors.kicad_sch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]
2023-06-04 KiCad Corrected the orientation of the impl PCBs
    [IOCACHE-128K_ZXspectrum_impl_narrow.kicad_pcb, RIO-128K_ZXspectrum_impl_narrow.kicad_pcb, SPI-Z80-BUS_ZXspectrum_impl.kicad_pcb]
2023-06-04 pcb2gcode corrected tool change possition settings
2023-06-04 pcb2gcode corrected milling spindle speed
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2023-06-06 Pcb2Gcode RIO prepared for fabrication
    [RIO-128K_ZXspectrum_impl_narrow-B_Cu.gbr, RIO-128K_ZXspectrum_impl_narrow-Edge_Cuts.gbr, RIO-128K_ZXspectrum_impl_narrow-F_Cu.gbr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]
2023-06-07 pcb2gcode updates zsafe drill depth cut feed speed
    [RIO-128K_ZXspectrum_impl_narrow-B_Cu.gbr, RIO-128K_ZXspectrum_impl_narrow-Edge_Cuts.gbr, RIO-128K_ZXspectrum_impl_narrow-F_Cu.gbr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]
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2023-06-23 Fixed RIOconfig control patterns
    [ESPTests.cpp, Z80Hardware_emulation.cpp, main.cpp]
2023-06-25 Fixed CACHE and SPI bugs
2023-06-27 KICAD IOCACHE fixed
    [IOCACHE-128K_ZXspectrum.kicad_sch, IOCACHE-128K_ZXspectrum_connectors.kicad_sch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]
2023-06-27 KiCad - Fixed GLUE (need to update concept v2)
    [CACHE CONTROL.kicad_sch, GLUE_ZXspectrum.kicad_sch, GLUE_ZXspectrum_connectors.kicad_sch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]
2023-06-27 KiCad SPI fixed
    [SPI-Z80-BUS_ZXspectrum.kicad_sch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]
2023-06-28 KiCad Conceptv2 broken dont use yet!
    [..dsn, ZXspectrum_Concept_v2-routed.dsn, ZXspectrum_Concept_v2.dsn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]
2023-07-01 Fixing everything with ThatOldNerd!
    [ESPTests.cpp, Z80Hardware_emulation.cpp, main.cpp]
2023-07-01 Code : massive refactor and fixing of Z80 emu side
    [Z80Hardware_emulation.cpp, main.cpp]
2023-07-04 CODE bug in the BUSRQ ISR
    [Z80Hardware_emulator.cpp]
2023-07-04 FIXED THE SPI BUS (stable)
    [ESPBUSInterface.cpp, ESPHAL.cpp, ESPHALDriverATmega.cpp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]
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2023-07-20 Simulation - SPI updates code and corrections
    [ESPHAL.cpp, ESPHALDriverATmega.cpp, ESPTests.cpp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]
2023-07-25 CODE & SIM Applied the SPI clock fix to 165s
    [ESPHALDriverATmega.cpp, ESPTests.cpp]
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2023-08-06 Shorten folder names
    [+.dsn, ..dsn, CACHE CONTROL.kicad_sch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]
2023-08-06 ignoring CNC files path too long for windows
    [IOCACHE-128K_ZXspectrum.kicad_sch, IOCACHE-128K_ZXspectrum_connectors.kicad_sch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]
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2023-08-23 SIMULIDE: Update to the simulation for GLUE fixes
    [main.cpp]
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2023-11-17 Fixed to the Simulation and Test Code
    [ESPBUSInterface.cpp, ESPHALDriverATmega.cpp, ESPTests.cpp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]
2023-11-18 FIX SPI CE signalling added
    [ESPHALDriverATmega.cpp]
2023-11-18 ROM test error message update
    [ESPTests.cpp]
2023-11-19 Fixed ESP_SPI_INT_CE start up LOW
    [ESPHAL.cpp, ESPHALDriverATmega.cpp, ESPTests.cpp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]
2023-11-19 SIM Corrected SPI control Bias wired wrong
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2023-11-20 RIO IOD Config Access correction
    [ESPHAL.cpp]
2023-11-22 Host reset function added
    [ESPHALDriverATmega.cpp]
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2023-11-25 Double send SPI on setup for Simulator bug
    [ESPHAL.cpp]
